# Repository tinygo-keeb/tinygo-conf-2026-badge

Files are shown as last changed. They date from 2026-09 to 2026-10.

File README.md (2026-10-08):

# TinyGo Conf 2026 Badge

[English](README.en.md)

TinyGo Conference 2026 向けバッジのハードウェア設計と TinyGo ファームウェアをまとめたリポジトリです。ESP32-S3-DevKit を中心に、ディスプレイ、入力デバイス、音声、赤外線、温湿度センサーなどを搭載しています。

## 主な機能

| 機能 | ハードウェア | ファームウェアの例 |
| --- | --- | --- |
| 表示 | ST7789 ディスプレイ | [`display`](firmware/examples/display)、[`demo`](firmware/examples/demo) |
| 入力 | ジョイスティック、スイッチ × 2 | [`input`](firmware/examples/input)、[`rhythm`](firmware/examples/rhythm) |
| 光と音 | RGB LED × 2、MAX98357 アンプとスピーカー | [`blink`](firmware/examples/blink)、[`audio`](firmware/examples/audio) |
| センサー・拡張 | AHT21B 温湿度センサー、Grove 互換 I2C コネクタ | [`aht21b`](firmware/examples/aht21b)、[`i2cscan`](firmware/examples/i2cscan) |
| 赤外線 | 赤外線 LED・受信モジュール | [`ir`](firmware/examples/ir)、[`irlearn`](firmware/examples/irlearn) |
| 無線通信 | ESP32-S3 の Wi-Fi・BLE | [`wifi-server`](firmware/examples/wifi-server)、[`ble-sensor`](firmware/examples/ble-sensor) |

全体の動作確認には [`selftest`](firmware/examples/selftest) を使えます。

## 組み立て

必要な部品と写真付きの組み立て手順は [ビルドガイド](hardware/build/build.md) を参照してください。

## ドキュメントとファイル

| パス | 内容 |
| --- | --- |
| [hardware/README.md](hardware/README.md) | 基板の構成、KiCad のセットアップ、製造データ |
| [hardware/build/build.md](hardware/build/build.md) | 部品一覧と写真付きの組み立て手順 |
| [hardware/tinygo-conf-2026.kicad_pro](hardware/tinygo-conf-2026.kicad_pro) | KiCad プロジェクト。回路図と基板レイアウトは同じディレクトリにあります |
| [firmware/README.md](firmware/README.md) | ビルド・書き込み方法、サンプル一覧、ピン割り当て、実装上の注意点 |
| [firmware/Makefile](firmware/Makefile) | サンプルのビルド確認や Wi-Fi サンプルの書き込み |

## 使い始める

### ハードウェア

KiCad 9.0 以降を使用します。KiCad ライブラリの一部はサブモジュールなので、リポジトリのルートで取得してください。

```sh
git submodule update --init --recursive
```

[KiCad プロジェクト](hardware/tinygo-conf-2026.kicad_pro) を開き、バッジの組み立てには [組み立てガイド](hardware/build/build.md) を参照してください。

### ファームウェア

TinyGo を用意し、ESP32-S3-DevKit を接続して以下を実行します。

```sh
cd firmware
tinygo flash --target esp32s3-box-3 --size short ./examples/blink
tinygo monitor --target esp32s3-box-3
```

全サンプルのビルド確認は `firmware/` で `make smoketest` を実行します。Wi-Fi・BLE の設定や各サンプルの使い方は [ファームウェアのREADME](firmware/README.md) を参照してください。

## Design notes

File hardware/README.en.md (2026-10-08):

# Hardware (tinygo-conf-2026)

[日本語](README.md)

This KiCad project defines the development board for TinyGo Conference 2026. It brings the display, audio, and input devices together on one board around an ESP32-S3-DevKit.

## Main components and features

- **ESP32-S3-DevKit** — main board mounted through pin sockets
- **ST7789 display** — SPI connection (CS / DC / RES / SCL / DIN), 8-pin connector
- **MAX98357 (Adafruit)** — I2S audio amplifier (BCLK / LRC / DIN) and speaker
- **Two RGB LEDs** — connected in series
- **Analog joystick (ALPS RKJXV122400R)** — X/Y axes and push button
- **Two push switches**
- **Infrared LED and receiver** — IR_LED / IR_DATA
- **4-pin I2C connector** — for external modules, with a Grove-compatible footprint
- **AHT21B** — temperature and humidity sensor

## Files

| Path | Description |
| --- | --- |
| `tinygo-conf-2026.kicad_pro` | KiCad project file |
| `tinygo-conf-2026.kicad_sch` | Schematic |
| `tinygo-conf-2026.kicad_pcb` | PCB layout |
| `tinygo-conf-2026-devkit/` | Manufacturing Gerber and drill files |
| `lib/` | Symbol and footprint libraries, including the submodules listed below |
| `lib/sglib.kicad_sym`, `lib/sglib.pretty/` | Custom libraries for the joystick, Grove connector, and other parts |
| `fp-lib-table`, `sym-lib-table` | Project library tables |

## Requirements

- KiCad 9.0 or later

## Setup

Some libraries are managed as Git submodules. Run this command from the repository root:

```sh
git submodule update --init --recursive
```

Then open `hardware/tinygo-conf-2026.kicad_pro` in KiCad.

### Submodules

| Path | Purpose | Source |
| --- | --- | --- |
| `lib/espressif` | ESP32 symbols | espressif/kicad-libraries |
| `lib/kbd` | ESP32-S3-DevKit symbols and more | foostan/kbd |
| `lib/MAX98357` | MAX98357 amplifier | besi/kicad-adafruit-MAX98357 |
| `lib/st7789` | ST7789 display | BennyLuca/Kicad_Components_Library |
| `lib/sparkfun` | SparkFun library | sparkfun/SparkFun-KiCad-Libraries |

## Manufacturing files

The `tinygo-conf-2026-devkit/` directory contains the complete two-layer board output: front and back copper, solder mask, paste, silkscreen, board outline, and PTH/NPTH drill files.

## Assembly

See the [build guide](build/build.en.md) for the parts list and illustrated instructions.

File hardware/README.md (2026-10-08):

# ハードウェア (tinygo-conf-2026)

[English](README.en.md)

TinyGo Conference 2026 向け開発ボード (devkit) の KiCad プロジェクトです。
ESP32-S3-DevKit を中心に、ディスプレイ・オーディオ・入力デバイスなどを 1 枚の基板にまとめています。

## 主な搭載部品・機能

- **ESP32-S3-DevKit** — メインボード (ピンソケット経由で搭載)
- **ST7789 ディスプレイ** — SPI 接続 (CS / DC / RES / SCL / DIN)、8 ピンコネクタ
- **MAX98357 (Adafruit)** — I2S オーディオアンプ (BCLK / LRC / DIN) + スピーカー
- **RGB LED × 2** — シリアル接続
- **アナログジョイスティック (ALPS RKJXV122400R)** — X / Y 軸 + プッシュボタン
- **プッシュスイッチ × 2**
- **赤外線 LED / 赤外線受信** — IR_LED / IR_DATA
- **I2C コネクタ (4 ピン)** — 外部モジュール接続用 (Grove 互換フットプリントあり)
- **AHT21B** — 温湿度センサー

## ファイル構成

| パス | 内容 |
| --- | --- |
| `tinygo-conf-2026.kicad_pro` | KiCad プロジェクトファイル |
| `tinygo-conf-2026.kicad_sch` | 回路図 |
| `tinygo-conf-2026.kicad_pcb` | 基板レイアウト |
| `tinygo-conf-2026-devkit/` | 製造用ガーバー・ドリルデータ |
| `lib/` | シンボル / フットプリントライブラリ (下記サブモジュール含む) |
| `lib/sglib.kicad_sym`, `lib/sglib.pretty/` | 自作ライブラリ (ジョイスティック、Grove コネクタなど) |
| `fp-lib-table`, `sym-lib-table` | プロジェクト用ライブラリテーブル |

## 必要環境

- KiCad 9.0 以降

## セットアップ

ライブラリの一部は git サブモジュールとして管理しています。リポジトリのルートで以下を実行してください。

```sh
git submodule update --init --recursive
```

その後 `hardware/tinygo-conf-2026.kicad_pro` を KiCad で開きます。

### サブモジュール一覧

| パス | 用途 | 取得元 |
| --- | --- | --- |
| `lib/espressif` | ESP32 系シンボル | espressif/kicad-libraries |
| `lib/kbd` | ESP32-S3-Devkit シンボルなど | foostan/kbd |
| `lib/MAX98357` | MAX98357 アンプ | besi/kicad-adafruit-MAX98357 |
| `lib/st7789` | ST7789 ディスプレイ | BennyLuca/Kicad_Components_Library |
| `lib/sparkfun` | SparkFun ライブラリ | sparkfun/SparkFun-KiCad-Libraries |

## 製造データ

`tinygo-conf-2026-devkit/` に 2 層基板のガーバーデータ (表裏の銅箔・レジスト・ペースト・シルク、外形、PTH/NPTH ドリル) 一式が出力済みです。

## 組み立て

部品一覧と写真付きの手順は [組み立てガイド](build/build.md) を参照してください。

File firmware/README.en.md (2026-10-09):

# Firmware

[日本語](README.md)

TinyGo firmware for the TinyGo Conference 2026 badge, based on the ESP32-S3-DevKit.

## Build and flash

From the repository root:

```sh
cd firmware
tinygo flash --target esp32s3-box-3 --size short ./examples/blink
tinygo monitor --target esp32s3-box-3
```

The `smoketest` target in `Makefile` lists the build command for each example on its own line. Run `make smoketest` to build them all into `out/`. To flash an example, copy its line and replace `build -o ./out/xxx.bin` with `flash`.

Wi-Fi examples embed the SSID and password at build time. The Makefile uses `YOUR_SSID` and `YOUR_PASSWORD` placeholders. Replace them with your values, or use `make flash-wifi-<name>` to supply credentials through Make variables or environment variables:

```sh
make flash-wifi-server SSID=yourssid PASS=yourpassword
# Environment variables also work (WIFI_SSID / WIFI_PASS, or SSID / PASS).
export WIFI_SSID=yourssid WIFI_PASS=yourpassword
make flash-wifi-server
# Manual command:
CGO_CFLAGS_ALLOW=-fno-short-enums tinygo flash --target esp32s3-box-3 --size short \
  -ldflags="-X main.ssid=yourssid -X main.password=yourpassword" ./examples/wifi-server
```

With TinyGo 0.43 or later, BLE examples build with the standard target used in the Makefile. Older TinyGo versions need the custom target `targets/esp32s3-box-3-ble.json` and `-tags espradio`. Run these commands from `firmware/` because the linker script path is relative to that directory. Add `-tags bledebug` to print Bluetooth ATT/HCI debug output over serial.

```sh
CGO_CFLAGS_ALLOW=-fno-short-enums tinygo flash --target esp32s3-box-3 --size short ./examples/ble-sensor
# For older TinyGo versions:
CGO_CFLAGS_ALLOW=-fno-short-enums tinygo flash --target ./targets/esp32s3-box-3-ble.json \
  -tags espradio --size short ./examples/ble-sensor
```

## Layout

| Path | Description |
| --- | --- |
| `badge/` | Pin assignments and helpers for initializing peripherals |
| `ws2812s3/` | WS2812B driver for the ESP32-S3 at 240 MHz |
| `i2s/` | 16-bit stereo audio output driver using ESP32-S3 I2S0 and GDMA |
| `wifi/` | Helper for connecting through espradio; resets and retries after a failure |
| `flashstore/` | Settings storage that reads and writes 64 KB of SPI flash starting at 0x1F0000 through ROM functions |
| `targets/` | Custom BLE target with an upstream TinyGo esp32s3.ld linker script |
| `examples/blink` | Cycle the WS2812B LEDs through rainbow colors |
| `examples/all` | Launcher for all 20 examples: logo on startup, SW1 opens the menu, joystick up/down selects, SW1 or joystick press starts, holding SW1+SW2 for one second returns from an example to the menu, and left in the menu returns to TOP. Menu movement uses buffered partial updates. See [the launcher README](examples/all/README.md) for build commands and controls. |
| `examples/display` | Show color bars and text on the ST7789 |
| `examples/input` | Print the SW1/SW2 and joystick states over serial |
| `examples/joyraw` | Measure raw joystick values and movement limits (min/max) |
| `examples/aht21b` | Print temperature and humidity readings |
| `examples/i2cscan` | Scan the Grove and AHT21B I2C buses |
| `examples/dht20` | Print readings from a Grove-connected DHT20 (AHT20-compatible) sensor |
| `examples/wifi-httpget` | Connect to Wi-Fi and fetch http://httpbin.org/get using net/http |
| `examples/wifi-server` | Serve AHT21B temperature and humidity readings over HTTP using httphi |
| `examples/wifi-joystick` | Show joystick X/Y and switch states live in a browser |
| `examples/ble-scanner` | Scan nearby BLE devices and print addresses, RSSI, and names |
| `examples/ble-sensor` | BLE peripheral with temperature and humidity (Environmental Sensing), color writes for two WS2812B LEDs, button notifications, and automatic/manual LED modes. Shows the chip-specific ID in its name and on the LCD |
| `examples/ble-sensor/webble.html` | Web Bluetooth control page for the BLE peripheral; open it in Chrome or Edge. It is also published at https://conf.tinygo-keeb.org/2026/conf2026badge/ |
| `examples/ir` | Receive NEC infrared signals and send one when a button is pressed |
| `examples/irlearn` | Learn, list, name, delete, save, and retransmit remote-control signals |
| `examples/audio` | Play notes, melodies, and beeps through the MAX98357 |
| `examples/audiotest` | Print I2S diagnostics and continuously play a 1 kHz sine wave |
| `examples/demo` | Full-feature demo combining the features above |
| `examples/rhythm` | Rhythm game: press five controls (joystick left, up or down, right, SW2, and SW1) as notes fall. The BGM is synthesized live; pitch corresponds to lane, and effects grow with the combo. EASY / NORMAL modes |
| `examples/slotgame` | Three-reel slot game controlled entirely with button_1 (SW1). Press to start, then press again to stop each reel from left to right. See [the game README](examples/slotgame/README.md) for controls and build commands. |
| `examples/selftest` | Check all onboard devices together. Buttons, joystick directions, AHT21B, infrared loopback, and I2S are checked automatically; the display shows ALL OK when complete. Check the LCD, LEDs, speaker, and Grove by sight or sound |

## Pin assignments

These assignments come from `../hardware/tinygo-conf-2026.kicad_sch`. Constants are in `badge/badge.go`.

| Function | Signal | GPIO | Notes |
| --- | --- | --- | --- |
| LCD ST7789 (J3) | SCL | 12 | SPI0 (FSPI) |
| | SDA (MOSI) | 11 | |
| | CS | 10 | |
| | DC | 5 | |
| | RES | 4 | |
| | BLK | - | Connected directly to 3V3 |
| I2S MAX98357 (U3) | BCLK | 45 | I2S0 (see below) |
| | LRC | 21 | |
| | DIN | 47 | |
| WS2812B x2 (D1, D2) | DIN | 16 | D1 -> D2 in series |
| Joystick (U2) | X | 7 | ADC1_CH6 |
| | Y | 6 | ADC1_CH5 |
| | BTN | 15 | Grounded when pressed; internal pull-up |
| SW1 | | 13 | Grounded when pressed; internal pull-up |
| SW2 | | 14 | Grounded when pressed; internal pull-up |
| IR LED (D5) | | 17 | High turns it on; modulated with 38 kHz PWM |
| IR receiver (J2) | DATA | 18 | |
| Grove I2C (J1) | SDA | 8 | I2C0 |
| | SCL | 9 | |
| AHT21B (J4) | SDA | 41 | I2C1 |
| | SCL | 42 | |

Expansion header J5 (2x8):

```
 1: 3V3     2: 3V3
 3: GPIO1   4: GPIO2
 5: GPIO3   6: GPIO38
 7: GPIO39  8: GND
 9: GND    10: GPIO40
11: GPIO41 12: GPIO42   (shared with AHT21B SDA/SCL)
13: GPIO45 14: GPIO46   (GPIO45 is shared with I2S BCLK)
15: GPIO48 16: VCC (5V)
```

## Notes

- **Target:** Use `esp32s3-box-3`. The `esp32s3-generic` target does not define
  `machine.CPUFrequency()` or the default SPI pins, so some drivers cannot build.
- **WS2812B:** On Xtensa, `tinygo.org/x/drivers/ws2812` only supports 80 and 160 MHz.
  The ESP32-S3 runs at 240 MHz, so `ws2812s3/` provides a bit-banging driver
  with timing for 240 MHz.
- **LCD flicker:** Drawing directly to the display makes individual updates
  visible. `badge.NewFramebuffer(display)` creates a full-screen offscreen
  buffer (RGB565, about 115 KB). Draw there, then call `Display()` to transfer
  it in one pass (see `examples/demo`). The buffer can also be passed directly
  to tinyfont and tinydraw.
- **I2C initialization:** During its final bus-clear step,
  `machine.I2C.Configure` waits indefinitely for a completion bit and may hang
  on a floating bus without pull-ups. Configure also overwrites pin settings,
  removing any internal pull-ups enabled beforehand. `badge.ConfigureI2C()`
  implements the same sequence with internal pull-up support and a finite
  wait. Both Grove (`ConfigureGroveI2C`, with internal pull-ups at 100 kHz)
  and AHT21B (`ConfigureSensorI2C`) use it.
- **I2C scanning:** TinyGo's ESP32 I2C driver does not report an address NACK
  as an error on reads. On writes, after a NACK it leaves unsent data in the
  TX FIFO, causing the next transaction to become a general call, which the
  AHT21B acknowledges. `badge.ProbeI2C()` therefore sends only the address
  byte through direct register access, then calls `badge.ResetI2C()` to reset
  the FSM and FIFO after a failure.
- **Joystick travel:** The joystick cap limits its movement. Raw ADC readings
  travel only about ±16000 to 17000 counts around the center, roughly half the
  full 0..65535 range. `badge.Joystick` normalizes with `Range` (default 16000),
  so a full deflection reaches 1000. If the range differs, measure it with
  `examples/joyraw` and adjust `Range`. Stationary noise is about ±100 counts,
  so `DeadZone` is set to 50 (equivalent to 800 counts).
- **USB serial:** Output from `print` is not sent until a newline. Long
  operations without a newline may appear to produce no output; use `println`
  at checkpoints.
- **Output in interrupts:** Callbacks such as those in infrared reception
  (irremote) run inside GPIO interrupts. Calling `println` there can stall USB
  serial output. Save the data in the callback and print it from the main
  loop instead (see `examples/ir`).
- **Flash storage:** TinyGo's machine package has no ESP32-S3 flash API.
  `flashstore/` calls the fixed-address ROM functions
  `esp_rom_spiflash_read/write/erase_sector/unlock` directly through CGo;
  the addresses come from ESP-IDF v5.1.2's esp32s3.rom.ld. It follows the
  same procedure as TinyGo's ESP32-C3 driver and calls the ROM functions
  with interrupts disabled. TinyGo writes 2 MB as the flash size in the image
  header, so the ROM driver rejects erase/write operations above 2 MB.
  The settings area therefore occupies the final 64 KB below 2 MB,
  starting at 0x1F0000. Reads also use ROM functions instead of the cache.
- **I2S (MAX98357):** TinyGo's machine package does not support ESP32-S3 I2S.
  The implementation in `i2s/` accesses registers directly, following the
  procedure from ESP-IDF v5.1's i2s_ll.h, gdma_ll.h, and i2s_std.c. ESP32-S3
  I2S can send data only through GDMA, so DMA buffers form a ring for
  continuous playback; `Write` fills them in turn. The ring keeps playing,
  so call `Silence()` (or `Stop()` on a `badge.ToneGenerator`) after playback.
  The format is Philips standard, 16-bit, two channels, MCLK = fs*256, and
  BCLK = fs*32 (16-bit slots; `Config.SlotBits` also allows 32). GDMA uses
  channel 0.
- **Wi-Fi:** The firmware uses `tinygo.org/x/espradio` (TinyGo 0.41 or later),
  which combines Espressif binary blobs with lneto, a pure-Go TCP/IP stack.
  The espradio C code requires `-fno-short-enums`, so builds need
  `CGO_CFLAGS_ALLOW=-fno-short-enums`; relevant Makefile lines set it.
  Embed the SSID and password with
  `-ldflags="-X main.ssid=... -X main.password=..."`. Without them, the
  example repeatedly reports `failure: ssid is empty` at startup. Wi-Fi
  code is then eliminated as dead code, making the binary unusually small.
  The HTTP server uses espradio's recommended `httphi`, which does not
  allocate heap space per request. `net/http` allocates about 10 KB per
  connection and can stall after long runs due to GC fragmentation (see
  espradio's README). Wireless initialization can happen only once: calling
  `NetConnect` again after a failure returns `already enabled`.
  `wifi.Connect()` waits five seconds after a failure, then soft-resets the
  chip with `badge.Reset()` and starts over. Just after closing a monitor,
  a previous session can remain on the access point and cause
  `auth expired`; this retry handles it. Merely importing espradio links
  initialization data even if unused, increasing flash use by about 170 KB
  and RAM use by about 160 KB. For that reason, Wi-Fi helpers live in
  the separate `wifi` package instead of `badge`.
- **BLE:** The firmware uses the espradio backend of
  `tinygo.org/x/bluetooth` (build tag `espradio`). TinyGo 0.43 and later
  apply that tag to ESP32 targets by default and include ESP32-S3 BT ROM
  symbols in the linker script, so the standard target works. Older
  versions, such as 0.42.0-dev, lack both and fail to link because the BLE
  blob (libbtdm_app.a) references about 1,000 ROM symbols, including
  `r_osi_funcs_p`. To support them, this repository includes upstream
  TinyGo's esp32s3.ld (retrieved from the dev branch on 2026-09-25) as
  `targets/esp32s3-ble.ld`. The custom target
  `targets/esp32s3-box-3-ble.json` inherits from esp32s3-box-3 and uses that
  script. With older TinyGo, specify this target and `-tags espradio`.
  The `linkerscript` path in a TinyGo target JSON is resolved relative to
  the current working directory (`firmware/`).
- **Badge identification:** `badge.SerialNumber()` returns a six-digit
  hexadecimal ID from the low three bytes of the chip-specific eFuse MAC
  address. The ble-sensor example advertises as
  `TinyGo Conf 2026 #XXXXXX` and displays the same ID on the LCD, making it
  possible to distinguish badges used together in a workshop.
- **Where espradio is imported:** TinyGo runs package initializers in
  lexicographic import-path order. After an initializer that cannot be
  evaluated at compile time (an espradio C call), subsequent package
  initializers run at runtime instead. This module's import path
  (`github.com/sago35/...`) sorts before `github.com/soypat/lneto` and
  `net/http`. Importing espradio from this module would move Unicode table
  initialization and similar work to runtime, increasing RAM use by about
  70 KB (measured: 115 KB to 240 KB). Therefore `wifi.Connect()` accepts
  a `netlink.Netlinker` rather than importing espradio, and each example's
  main package creates the `Esplink`.
- **MAX98357 SD pin:** The pin is unconnected in the schematic. On an
  Adafruit module, its onboard 1 MΩ pull-up puts SD at about 0.45 V with
  Vin = 5 V (stereo average mode), but some modules did not work in this
  configuration. A module with SD tied directly to Vin (left channel only)
  was tested successfully. The firmware sends the same audio on L and R,
  so both modes sound the same. A future board revision should provide
  the SD pull-up on the board.

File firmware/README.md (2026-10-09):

# firmware

[English](README.en.md)

TinyGo Conference 2026 バッジ (ESP32-S3-DevKit ベース) の TinyGo ファームウェア。

## ビルド・書き込み

```sh
cd firmware
tinygo flash --target esp32s3-box-3 --size short ./examples/blink
tinygo monitor --target esp32s3-box-3
```

`Makefile` の `smoketest` に全 example のビルドコマンドを 1 行ずつそのまま書いてある
(`make smoketest` で全部ビルドして `out/` に出力する)。書き込みたいときは該当する行を
コピーして、`build -o ./out/xxx.bin` を `flash` に変えて実行する。

Wi-Fi の example は SSID とパスワードをビルド時に埋め込む。Makefile の行は
`YOUR_SSID` / `YOUR_PASSWORD` のプレースホルダなので、自分のものに書き換えるか、
環境変数から埋め込む `make flash-wifi-<name>` を使う。

```sh
make flash-wifi-server SSID=yourssid PASS=yourpassword
# 環境変数でも可 (WIFI_SSID / WIFI_PASS、または SSID / PASS)
export WIFI_SSID=yourssid WIFI_PASS=yourpassword
make flash-wifi-server
# 手動なら
CGO_CFLAGS_ALLOW=-fno-short-enums tinygo flash --target esp32s3-box-3 --size short \
  -ldflags="-X main.ssid=yourssid -X main.password=yourpassword" ./examples/wifi-server
```

BLE の example は TinyGo 0.43 以降なら Makefile の行のとおり通常のターゲットでビルドできる。
それより古い TinyGo では専用ターゲット (`targets/esp32s3-box-3-ble.json`) と
`-tags espradio` を指定する (firmware/ で実行。リンカスクリプトのパスは firmware/ からの相対)。
`-tags bledebug` を足すと bluetooth パッケージのデバッグ出力 (ATT/HCI の処理) がシリアルに出る。

```sh
CGO_CFLAGS_ALLOW=-fno-short-enums tinygo flash --target esp32s3-box-3 --size short ./examples/ble-sensor
# 古い TinyGo なら
CGO_CFLAGS_ALLOW=-fno-short-enums tinygo flash --target ./targets/esp32s3-box-3-ble.json \
  -tags espradio --size short ./examples/ble-sensor
```

## 構成

全サンプルを選択して実行するには `make flash-all` を使う。
`examples/all` は起動時にロゴを表示し、SW1で選択画面、Joystick上下で選択、
SW1またはJoystick押し込みで起動する。実行中はSW1＋SW2を1秒同時長押しして選択画面へ戻り、
選択画面でJoystick左に倒すとTOPへ戻る。
Wi-Fi設定や統合版での入力の違いは [examples/all/README.md](examples/all/README.md) を参照。

| パス | 内容 |
| --- | --- |
| `badge/` | ピン割り当てと各ペリフェラルの初期化ヘルパー |
| `ws2812s3/` | ESP32-S3 (240MHz) 用 WS2812B ドライバ |
| `i2s/` | ESP32-S3 の I2S0 + GDMA を使った 16bit ステレオ音声出力ドライバ |
| `wifi/` | espradio で Wi-Fi に接続するヘルパー (失敗時はリセットして再試行) |
| `flashstore/` | ROM 関数で SPI フラッシュの一部 (0x1F0000 から 64KB) を読み書きする設定保存用パッケージ |
| `targets/` | BLE 用のカスタムターゲット (アップストリーム TinyGo の esp32s3.ld を同梱) |
| `examples/blink` | WS2812B を虹色に点灯 |
| `examples/all` | 全20サンプルの統合ランチャー。ロゴ画面、Joystickで選択、実行中はSW1＋SW2を1秒同時長押しで選択画面へ戻る |
| `examples/display` | ST7789 にカラーバーと文字を表示 |
| `examples/input` | SW1/SW2 とジョイスティックの状態をシリアル出力 |
| `examples/joyraw` | ジョイスティックの生値と可動範囲 (min/max) を計測してシリアル出力 |
| `examples/aht21b` | 温湿度センサーの値をシリアル出力 |
| `examples/i2cscan` | Grove / AHT21B の I2C バスをスキャン |
| `examples/dht20` | Grove につないだ DHT20 (AHT20 互換) の温湿度をシリアル出力 |
| `examples/wifi-httpget` | Wi-Fi に接続して http://httpbin.org/get を取得 (net/http) |
| `examples/wifi-server` | Wi-Fi に接続して AHT21B の温湿度を返す HTTP サーバー (httphi) |
| `examples/wifi-joystick` | ジョイスティックの XY とスイッチの状態をブラウザにリアルタイム表示 |
| `examples/ble-scanner` | BLE で周囲のデバイスをスキャンしてアドレス、RSSI、名前を表示 |
| `examples/ble-sensor` | BLE ペリフェラル。温湿度 (Environmental Sensing)、WS2812B 2 個の色書き込み、ボタン通知、LED の自動/手動モード。名前と LCD にチップ固有の ID を表示 |
| `examples/ble-sensor/webble.html` | 上記に Web Bluetooth で接続して操作するページ (Chrome / Edge で開く)。https://conf.tinygo-keeb.org/2026/conf2026badge/ で公開している |
| `examples/ir` | 赤外線受信 (NEC) と、ボタン押下で赤外線送信 |
| `examples/irlearn` | リモコンの信号を学習して送信するアプリ。一覧、登録、名前編集、削除。フラッシュに保存 |
| `examples/audio` | MAX98357 から音階・メロディ・ビープを鳴らす |
| `examples/audiotest` | I2S の動作確認用。診断出力を出したあと 1kHz の正弦波を鳴らし続ける |
| `examples/demo` | 上記をまとめた全機能デモ |
| `examples/rhythm` | 音ゲー。上から降ってくるノーツに合わせて 5 つのキー (ジョイスティックの左、上か下、右と SW2、SW1) を押す。BGM はその場で合成し、メロディの音の高さとレーンが対応している。コンボ数に応じて画面の演出が増える。EASY / NORMAL |
| `examples/slotgame` | 3リールの目押しスロット。button_1（SW1）で開始し、押すたびに左 → 中央 → 右の順にリールを止める。[操作・ビルド方法](examples/slotgame/README.md) |
| `examples/selftest` | 基板上の全デバイスを一度に動作確認するセルフテスト。ボタン、ジョイスティック上下左右、AHT21B、赤外線の自己受信、I2S を自動判定し、すべて済むと ALL OK。LCD、LED、スピーカー、Grove は画面の表示と音で目視確認 |

## ピン割り当て

`tinygo-conf-2026.kicad_sch` から抽出。定数は `badge/badge.go` にある。

| 機能 | 信号 | GPIO | 備考 |
| --- | --- | --- | --- |
| LCD ST7789 (J3) | SCL | 12 | SPI0 (FSPI) |
| | SDA (MOSI) | 11 | |
| | CS | 10 | |
| | DC | 5 | |
| | RES | 4 | |
| | BLK | - | 3V3 直結 |
| I2S MAX98357 (U3) | BCLK | 45 | I2S0 (後述) |
| | LRC | 21 | |
| | DIN | 47 | |
| WS2812B x2 (D1, D2) | DIN | 16 | D1 -> D2 直列 |
| ジョイスティック (U2) | X | 7 | ADC1_CH6 |
| | Y | 6 | ADC1_CH5 |
| | BTN | 15 | 押下で GND、内部プルアップ |
| SW1 | | 13 | 押下で GND、内部プルアップ |
| SW2 | | 14 | 押下で GND、内部プルアップ |
| 赤外線 LED (D5) | | 17 | High で点灯、PWM 38kHz で変調 |
| 赤外線受信 (J2) | DATA | 18 | |
| Grove I2C (J1) | SDA | 8 | I2C0 |
| | SCL | 9 | |
| AHT21B (J4) | SDA | 41 | I2C1 |
| | SCL | 42 | |

拡張ヘッダ J5 (2x8):

```
 1: 3V3     2: 3V3
 3: GPIO1   4: GPIO2
 5: GPIO3   6: GPIO38
 7: GPIO39  8: GND
 9: GND    10: GPIO40
11: GPIO41 12: GPIO42   (AHT21B SDA/SCL と共用)
13: GPIO45 14: GPIO46   (GPIO45 は I2S BCLK と共用)
15: GPIO48 16: VCC (5V)
```

## 注意点

- **ターゲット**: `esp32s3-box-3` を使う。`esp32s3-generic` は `machine.CPUFrequency()`
  や SPI のデフォルトピンが定義されておらず、drivers の一部がビルドできない。
- **WS2812B**: `tinygo.org/x/drivers/ws2812` は xtensa では 80/160MHz のみ対応で、
  ESP32-S3 は 240MHz で動作するため使えない。`ws2812s3/` に 240MHz 用の
  タイミングでビットバンギング実装を置いている。
- **LCD のちらつき**: ディスプレイに直接描くと部分ごとの書き換えが見えてちらつく。
  `badge.NewFramebuffer(display)` で 1 画面分 (RGB565、約 115KB) のオフスクリーンバッファを
  作り、そこに描いてから `Display()` で一括転送する (`examples/demo` 参照)。tinyfont や
  tinydraw の描画先としてそのまま渡せる。
- **I2C 初期化**: `machine.I2C.Configure` は最後のバスクリアで完了ビットを無限に待つため、
  プルアップのない (浮いた) バスでは止まることがある。また Configure はピン設定を上書きするので
  事前に内部プルアップを有効にしても外れる。`badge.ConfigureI2C()` は同じ手順を内部プルアップ
  対応と有限待ちで自前実装したもので、Grove (`ConfigureGroveI2C`、内部プルアップ有効、100kHz) と
  AHT21B (`ConfigureSensorI2C`) はこれを使う。
- **I2C スキャン**: TinyGo の ESP32 I2C ドライバは読み出し時のアドレス NACK をエラーにせず、
  書き込みでは NACK 後に未送信データが TX FIFO に残って次のトランザクションがジェネラルコール
  になる (AHT21B はこれに ACK する)。そのため `badge.ProbeI2C()` はレジスタを直接操作して
  アドレスバイトのみを送り、失敗時は `badge.ResetI2C()` で FSM と FIFO をリセットしている。
- **ジョイスティックの可動範囲**: スティックはハット側で可動範囲を絞ってあり、ADC の生値は中心から
  ±16000..17000 カウント (全域 0..65535 の約半分) しか動かない。`badge.Joystick` は `Range` (既定 16000)
  で正規化するので、いっぱい倒すと 1000 に届く。範囲が変わったら `examples/joyraw` で計測して `Range` を直す。
  静止時のノイズは ±100 カウント程度なので `DeadZone` は 50 (= 800 カウント) にしてある。
- **USB シリアル**: `print` の出力は改行まで送られない。改行なしで長い処理をすると
  何も表示されないように見えるので、区切りには `println` を使う。
- **割り込み内での出力**: 赤外線受信 (irremote) などのコールバックは GPIO 割り込みの中で呼ばれる。
  その中で `println` を使うと USB シリアル出力が止まることがあるので、割り込み内ではデータを
  保存するだけにしてメインループで出力する (`examples/ir` 参照)。
- **フラッシュへの保存**: TinyGo の machine パッケージには ESP32-S3 用のフラッシュ API が無いので、
  `flashstore/` は ROM に固定アドレスで存在する `esp_rom_spiflash_read/write/erase_sector/unlock`
  を CGo から直接呼ぶ (アドレスは ESP-IDF v5.1.2 の esp32s3.rom.ld)。手順は TinyGo の
  ESP32-C3 用ドライバと同じで、割り込み禁止のまま ROM 関数を呼ぶ。TinyGo のイメージヘッダは
  フラッシュサイズを 2MB と書くので ROM ドライバは 2MB を超える erase/write を拒否する。そのため
  保存領域は 2MB 未満の末尾 (0x1F0000 から 64KB) に置く。読み出しもキャッシュ経由ではなく
  ROM 関数で行う。
- **I2S (MAX98357)**: TinyGo の machine パッケージは ESP32-S3 の I2S を未サポート。
  `i2s/` にレジスタ直叩きで実装している (ESP-IDF v5.1 の i2s_ll.h / gdma_ll.h / i2s_std.c の
  手順を移植)。ESP32-S3 の I2S は GDMA 経由でしか送れないため、DMA バッファをリング状につないで
  連続送信し、`Write` はそのバッファを順に埋める。リングは再生され続けるので、鳴らし終えたら
  `Silence()` (badge.ToneGenerator なら `Stop()`) で無音にすること。フォーマットは Philips 標準、
  16bit、2ch、MCLK = fs*256、BCLK = fs*32 (スロット幅 16。`Config.SlotBits` で 32 も可)。
  GDMA はチャネル 0 を使う。
- **Wi-Fi**: `tinygo.org/x/espradio` (TinyGo 0.41 以降、Espressif のバイナリブロブ + 純 Go の
  TCP/IP スタック lneto) を使う。espradio の C コードが `-fno-short-enums` を要求するので、
  ビルド時に環境変数 `CGO_CFLAGS_ALLOW=-fno-short-enums` が必要 (Makefile の該当行に前置してある)。
  SSID/パスワードは `-ldflags="-X main.ssid=... -X main.password=..."` で埋め込む。埋め込まないと
  example は起動時に `failure: ssid is empty` を繰り返す (このとき Wi-Fi のコードは
  デッドコードとして落ちるので、バイナリが極端に小さくなる)。HTTP サーバーは espradio 推奨の
  `httphi` (リクエストごとにヒープを使わない) を使う。`net/http` は接続ごとに約 10kB を
  ヒープに確保するため、長時間動かすと GC の断片化で止まることがある (espradio の README 参照)。
  espradio は無線の初期化を一度しかできず、接続に失敗したあと `NetConnect` を呼び直しても
  `already enabled` で失敗する。`wifi.Connect()` は失敗時に 5 秒待ってチップをソフトリセット
  (`badge.Reset()`) し、最初からやり直す。モニタを閉じた直後などは AP 側に前のセッションが残って
  `auth expired` になることがあるが、この再試行でつながる。
  espradio を import するだけで (使わなくても) 初期化データがリンクされ、フラッシュ約 170KB、
  RAM 約 160KB が増えるので、Wi-Fi のヘルパーは `badge` ではなく別パッケージ `wifi` に置いている。
- **BLE**: `tinygo.org/x/bluetooth` の espradio バックエンド (ビルドタグ `espradio`) を使う。
  TinyGo 0.43 以降は ESP32 ターゲットに `espradio` タグが標準で付き、ESP32-S3 の BT ROM
  シンボルもリンカスクリプトに含まれるので、通常のターゲットでビルドできる。
  それより古い TinyGo (0.42.0-dev など) ではどちらも無く、espradio の BLE ブロブ
  (libbtdm_app.a) が参照する ROM シンボル (`r_osi_funcs_p` など約 1000 個) でリンクに失敗する。
  その場合のために、アップストリーム TinyGo (dev ブランチ、2026-09-25 取得) の `esp32s3.ld` を
  `targets/esp32s3-ble.ld` として同梱し、`targets/esp32s3-box-3-ble.json` (esp32s3-box-3 を継承)
  から参照している。古い TinyGo ではこのカスタムターゲットと `-tags espradio` を指定する。
  TinyGo のターゲット JSON の `linkerscript` は cwd (firmware/) からの相対パスで解決される。
- **バッジの識別**: `badge.SerialNumber()` は eFuse の MAC アドレス (チップ固有) の下位 3 バイトを
  16 進 6 桁にした ID を返す。ble-sensor はアドバタイズ名を `TinyGo Conf 2026 #XXXXXX` にし、
  同じ ID を LCD に表示するので、ワークショップで複数のバッジが同時に動いていても見分けられる。
- **espradio の import 位置**: TinyGo はパッケージの init を import パスの辞書順に実行し、
  コンパイル時に評価できない init (espradio の C 呼び出し) に当たると、それ以降のパッケージの
  init を実行時に回す。このモジュール (`github.com/sago35/...`) は `github.com/soypat/lneto` や
  `net/http` より辞書順で前なので、このモジュール内のパッケージから espradio を import すると
  unicode などのテーブル初期化が実行時に回り、RAM が約 70KB 増える (実測: 115KB → 240KB)。
  そのため `wifi.Connect()` は espradio を import せず `netlink.Netlinker` を受け取り、
  `Esplink` の生成は example の main で行う。
- **MAX98357 の SD ピン**: 回路図では未接続。Adafruit 製モジュールは基板上の 1MΩ でプルアップされ
  Vin=5V なら SD が約 0.45V (ステレオ平均モード) になるが、これで動かない個体があった。
  SD を Vin に直結 (左チャネルのみ) したモジュールで動作確認済み。ファームウェアは L/R に同じ
  データを流すのでどちらのモードでも音は同じ。次の基板では SD のプルアップを基板側に持たせたい。

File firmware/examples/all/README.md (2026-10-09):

# all

`firmware/examples` の20本を、1つのファームウェアから選択して実行します。
`slotgame` は3リールの目押しスロットです。button_1（SW1）で開始し、押すたびに
左 → 中央 → 右の順にリールを止めます（[操作説明](../slotgame/README.md)）。

## 操作

| 画面 | 操作 | 動作 |
| --- | --- | --- |
| TOP | 起動時 | `img/logo.jpg` を240×240のLCDに表示 |
| TOP | `button_1` / SW1 | プログラム選択画面を開く |
| 選択画面 | Joystick 上・下 | 選択を移動。長く倒すと連続移動し、一覧の端で折り返す |
| 選択画面 | SW1 またはJoystick押し込み | 選択中のプログラムを起動 |
| 選択画面・起動待ち | Joystick 左 | TOPへ戻る |
| プログラム実行中 | SW1＋SW2を1秒同時長押し | 本体をリセットしてプログラム選択画面へ戻る |

起動時はJoystickを中立にしてください。プログラムを選んだ後も、ボタンと
Joystickを離してから実行を開始します。各プログラムのSW1/SW2などの操作は
元のexampleと同じです。シリアル出力だけのexampleでは、LCDに実行中の名前と
選択画面へ戻る操作を表示します。戻ると直前に実行していたプログラムが選択され、
Joystickとボタンを離してから次の操作を受け付けます。

実行中はJoystickの上下左右・押し込みを各プログラムで使えます。
`rhythm` の左レーンはJoystick左、`irlearn` の名前編集は左右でカーソル移動など、
単独版と同じ操作です。戻るときはSW1とSW2を両方押した状態で1秒待ち、
選択画面が表示されたらボタンを離してください。途中で片方を離すと長押しの
時間を数え直します。

選択の上下移動では全画面を消去せず、変更した行と選択番号を更新します。
文字と背景を約13.4KBのバッファに描き終えてから転送するため、スクロールでも
消去途中の画面が見えるちらつきを抑えます。

実行中のプログラムから戻る際は、音声DMA、赤外線割り込み、HTTPサーバーや
BLE/Wi-Fiの処理を残さないため、本体をリセットします。戻り先と選択位置はRTCの
レジスタに一時的に保存し、再起動後に選択画面を開きます。通常の電源投入時は
ロゴ画面になります。`irlearn` の保存済み
データは残り、`rhythm` のベストスコアなどRAMだけの状態は初期化されます。
Wi-Fi接続失敗時も既存の `wifi.Connect` によるリセットでTOPへ戻ります。

## ビルド・書き込み

`firmware/` で実行します。全機能を含むため `CGO_CFLAGS_ALLOW` が必要です。

```sh
make build-all
make flash-all
tinygo monitor --target esp32s3-box-3
```

Wi-Fiを利用するときはSSIDとパスワードを指定します。3つのWi-Fiプログラムが
同じ設定を使います。未指定でもTOPや他のプログラムを利用でき、Wi-Fiを選ぶと
設定が必要であることをLCDに表示します。

```sh
make build-all SSID=yourssid PASS=yourpassword
make flash-all SSID=yourssid PASS=yourpassword
# WIFI_SSID / WIFI_PASS 環境変数でも指定できます。
```

手動でビルドする場合:

```sh
mkdir -p out
CGO_CFLAGS_ALLOW=-fno-short-enums tinygo build -o ./out/all.bin \
  --target esp32s3-box-3 --size short \
  -ldflags="-X main.ssid=yourssid -X main.password=yourpassword" ./examples/all
```

BLE用のROMシンボルを含まない古いTinyGoでは、既存のカスタムターゲットを使います。

```sh
CGO_CFLAGS_ALLOW=-fno-short-enums tinygo build -o ./out/all.bin \
  --target ./targets/esp32s3-box-3-ble.json -tags espradio --size short \
  -ldflags="-X main.ssid=yourssid -X main.password=yourpassword" ./examples/all
```

## 元のexample・ロゴを変更したとき

元のexampleはそれぞれ単独でビルドできます。`example_*.go` と `programs.go` は
元のソースを名前空間を分けて取り込んだ生成ファイルです。変更後は次を実行します。
新しいexampleも、隣のディレクトリに `main` 関数を置けば一覧に追加されます。
`*_test.go` は統合せず、`//go:embed` で指定された画像は `assets/<example>/` に
コピーします。画像の指定はワイルドカードを含まない相対ファイルパスにしてください。

```sh
go generate ./examples/all
```

`img/logo.jpg` は元画像です。生成処理では拡張子によらずJPEG/PNGの内容を判別し、
縦横比を保って240×240のRGB565に縮小した `img/logo.rgb565` を作ります。
ファームウェアにはこの約115KBの変換済み画像を埋め込みます。画像のデコードは
PCで行い、LCDへの転送は16行ずつなので、大きな元画像を本体のRAMに展開しません。

確認コマンド:

```sh
make check-all
make build-all SSID=buildcheck PASS=buildcheck
```

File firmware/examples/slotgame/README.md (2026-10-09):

# slotgame

[sat0ken/tinygo-slotgame](https://github.com/sat0ken/tinygo-slotgame) を
TinyGo Conference 2026 バッジ（ESP32-S3、ST7789 240×240）に移植した
3リールの目押しスロットです。

## 操作

| 操作 | 動作 |
| --- | --- |
| 停止中にbutton_1（SW1） | ゲーム開始（3クレジット消費） |
| 回転中にSW1を押す | 左 → 中央 → 右の順に、1回につき1リールを止める |
| GAME OVER中にSW1 | 50クレジットに戻す。もう一度押すとゲーム開始 |
| `all` から起動した場合、SW1＋SW2を1秒同時長押し | プログラム選択画面へ戻る |

ゲームの操作はすべてbutton_1（SW1）です。押すたびに一度離してください。
長押しでは次のリールは止まりません。リール下の `SW1` ラベルは、次に止める
リールが赤、順番待ちが暗い赤、停止したリールが灰色になります。
開始直後の300msは停止できません。

リール配列は固定で乱数は使いません。押してから次のコマ境界まで、最大1コマ
滑って停止します。中段の赤い線に図柄がそろうと、次の配当になります。

| 中段の役 | 配当 |
| --- | --- |
| 7 × 3 | 100 |
| BAR × 3 | 50 |
| TinyGoロゴ × 3 | 25 |
| 茶色のGopher × 3 | 15 |
| チェリー × 3 | 10 |
| 青いGopher × 3 | 8 |
| 左リールがチェリー | 2 |

TinyGoロゴは各リールに1個ずつ入っています。

最初に当てはまる役だけを払い出し、残りが3クレジット未満ならGAME OVERです。
クレジットはRAMに保持するため、電源を切ったり `all` の選択画面へ戻ったりすると
初期化されます。元のゲームと同様に効果音はありません。

## ビルド・書き込み

`firmware/` で実行します。

```sh
make build-slotgame
make flash-slotgame
# 手動で書き込む場合
tinygo flash --target esp32s3-box-3 --size short ./examples/slotgame
```

`make flash-all` で書き込む統合版にも `slotgame` が含まれます。

## テスト・画面確認

```sh
make check-slotgame
go test ./examples/slotgame -run 'TestPreview|TestTinyGoBonus' -preview -preview-dir /tmp/slotgame-preview
```

`slot.go` はハードウェアに依存せず、配当・停止位置・ボタンの押下・ゲーム進行・
描画範囲をホストのGoで検証できます。描画用RAMは図柄6枚とリール1本分の約63KBで、
全画面のフレームバッファは確保しません。

TinyGoロゴの元画像は `img/tinygo.png`、組み込み用の画像は `img/tinygo.rgba` です。
元画像を変更した場合は、次のコマンドで高さ44pxのスプライトを生成します。

```sh
cd examples/slotgame
GO111MODULE=off go run ./tools/gensprite -h 44 -o img/tinygo.rgba img/tinygo.png
cd ../..
go generate ./examples/all
```

## 移植元・画像のクレジット

ゲーム本体、テスト、Gopherスプライトの移植元は
[tinygo-slotgame の e61ecf541d6ef2643899a1041f0d8602801aa867](https://github.com/sat0ken/tinygo-slotgame/tree/e61ecf541d6ef2643899a1041f0d8602801aa867)
です。LCD初期化・ボタン入力を `badge` の実装に置き換え、1ボタン操作を有効にし、
操作表示をSW1に変更しています。スプライトは移植元の生成済みデータを使っています。

The Go gopher was designed by [Renée French](https://reneefrench.blogspot.com/),
licensed under [CC BY 4.0](https://creativecommons.org/licenses/by/4.0/).

TinyGoロゴには[指定された画像](https://encrypted-tbn0.gstatic.com/images?q=tbn:ANd9GcSPeG0euLXxf-9uQ4XR_4dmq32-PiGb-mflkWEAVzMg3Q&s=10)
を使用し、縦横比を保って52×44pxに縮小しています。

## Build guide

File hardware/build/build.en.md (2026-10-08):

## TinyGo Conf 2026 Badge Build Guide

[日本語](build.md)

This guide explains how to assemble the badge board distributed at TinyGo Conference 2026.
The required parts are listed below. Please provide your own soldering iron and other assembly tools.

### Parts

You will need the following parts:

- ESP32-S3 DevKit

https://akizukidenshi.com/catalog/g/g131148/

- Joystick

https://akizukidenshi.com/catalog/g/g115951/

- ST7789 display

https://akizukidenshi.com/catalog/g/g131019/

- One current-limiting resistor

https://akizukidenshi.com/catalog/g/g116332/

- Two key switches

https://shop.yushakobo.jp/collections/all-switches

- Two keycaps

https://shop.yushakobo.jp/collections/keycaps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

- Two switch sockets

https://shop.yushakobo.jp/products/a01ps?variant=37665172521121

- MAX98357A

https://amzn.asia/d/054giKgU

- RGB LEDs (use two from the pack of five)

https://akizukidenshi.com/catalog/g/g115478/

- Infrared receiver module

https://akizukidenshi.com/catalog/g/g131157/

- Infrared LED

https://akizukidenshi.com/catalog/g/g112612/

- AHT21B temperature and humidity sensor

https://akizukidenshi.com/catalog/g/g130222/

- Two 20-pin socket strips

https://akizukidenshi.com/catalog/g/g103077/

- Two 2-pin socket strips

https://akizukidenshi.com/catalog/g/g110097/

### Assembly

#### LEDs / SK6812MINI-E

Start with the LEDs. Turn the board over and solder the surface-mount SK6812 LEDs to the back.

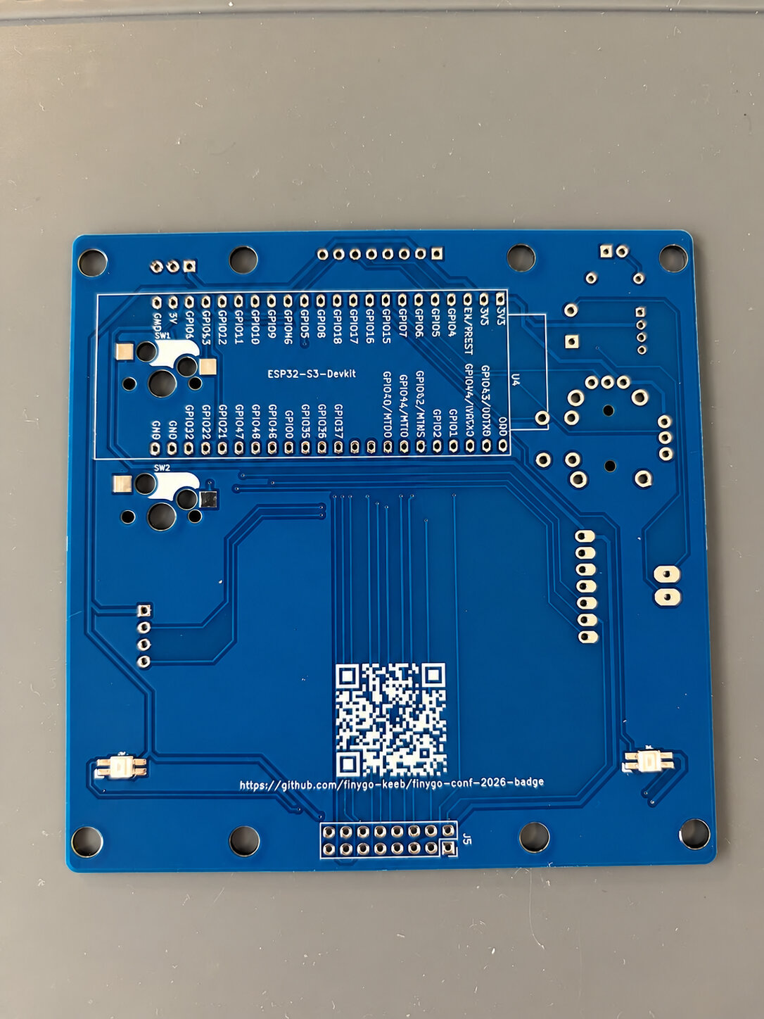
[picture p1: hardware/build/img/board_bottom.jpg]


The SK6812 has a specific orientation. Look closely at the LED and you will see one corner cut at a 45-degree angle.

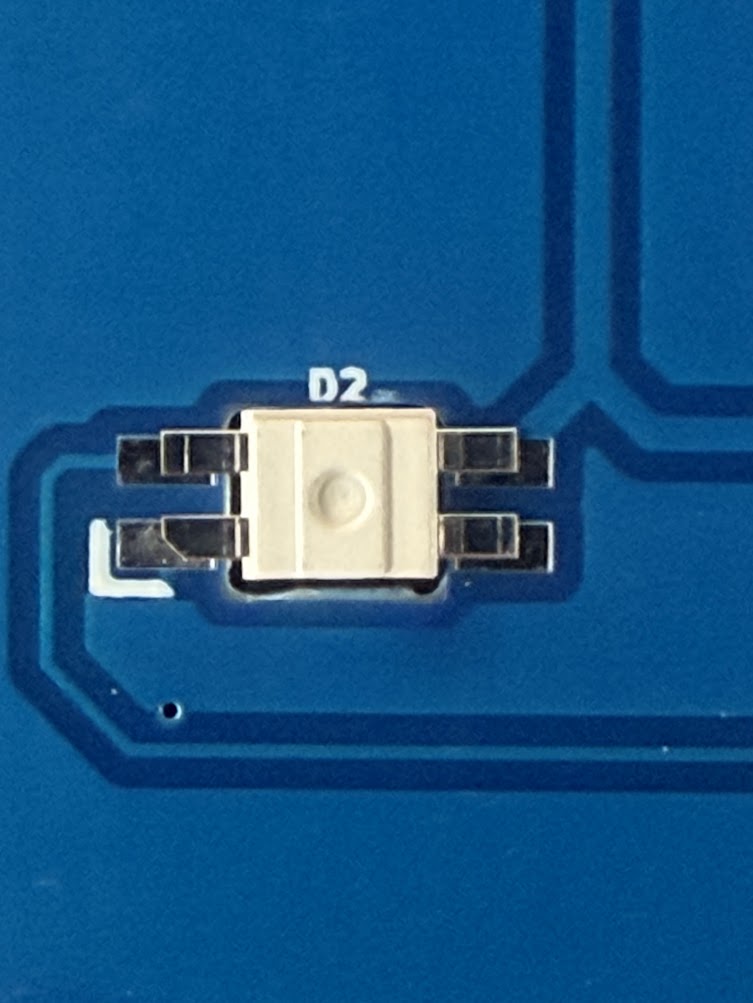
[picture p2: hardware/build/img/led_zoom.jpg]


On the back of the board, a white L-shaped marking shows where each LED belongs.
Align the LED's cut corner with the white L. If either LED faces the wrong way, the LEDs will not light, so check their orientation before soldering.

Place both LEDs in the correct orientation, then solder them.

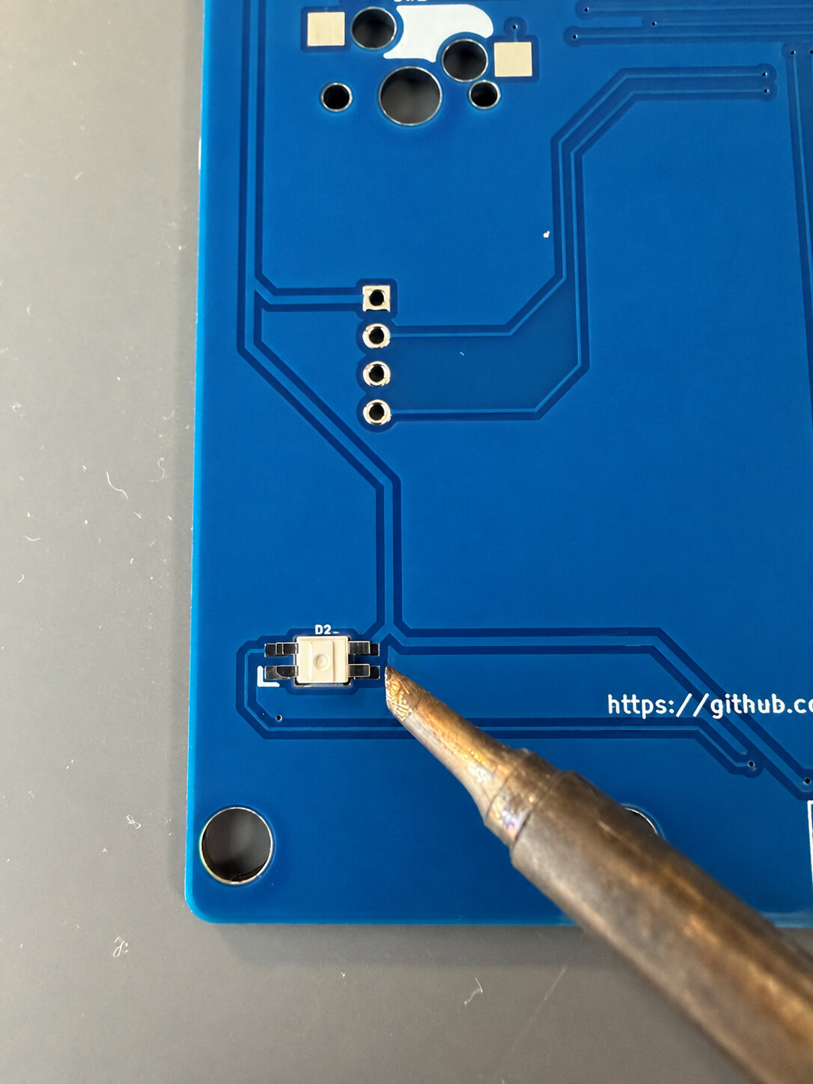
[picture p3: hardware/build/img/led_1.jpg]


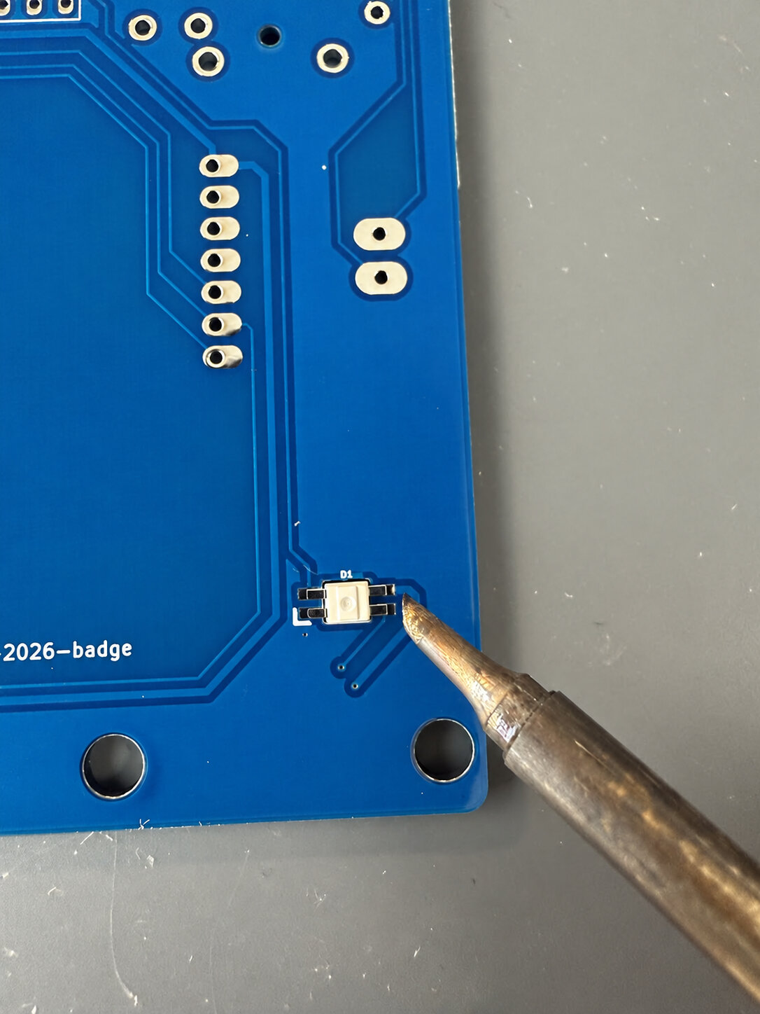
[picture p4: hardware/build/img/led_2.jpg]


Tip: Pre-tinning the pads can make it easier to solder the LEDs, though it is not required.

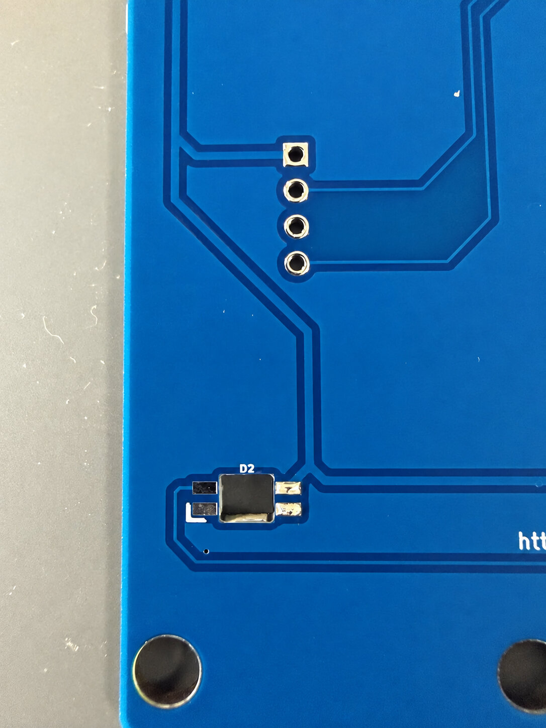
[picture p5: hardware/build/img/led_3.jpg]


Solder all four connections.

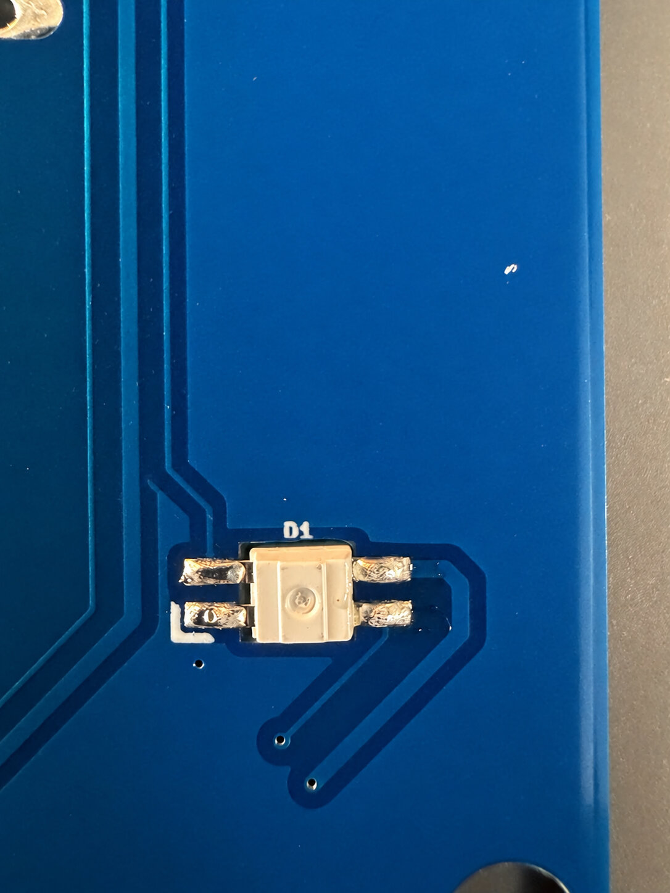
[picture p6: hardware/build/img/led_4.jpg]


#### Switch sockets

Install the switch sockets. Remove them from their packaging and place them on the board according to the silkscreen.

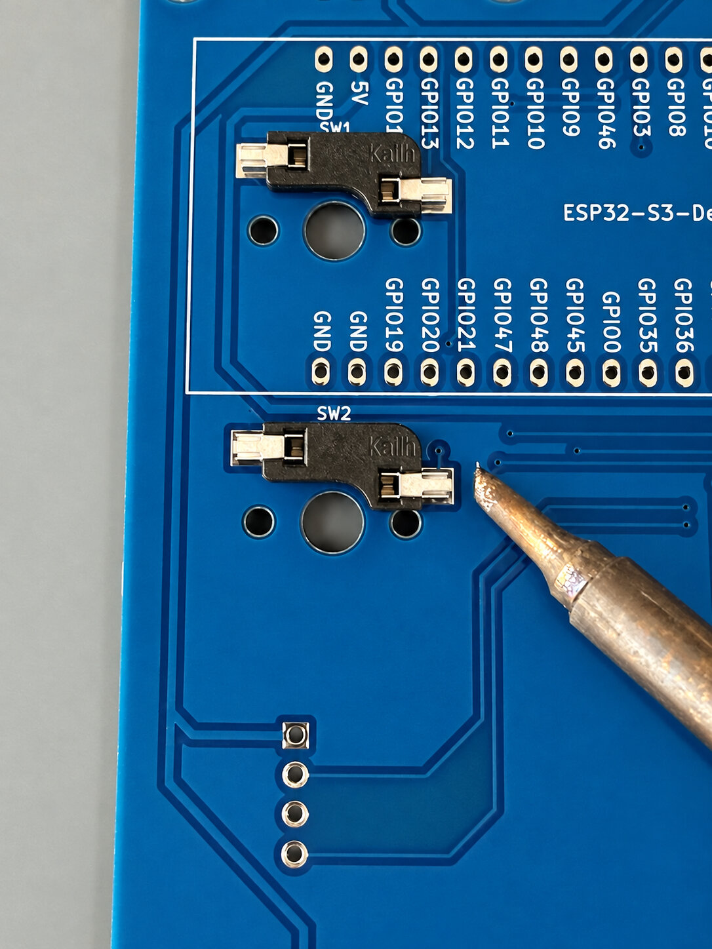
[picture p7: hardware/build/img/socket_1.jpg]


Apply the soldering iron from the side and feed solder into the joint. Check carefully that each socket is soldered to the board.

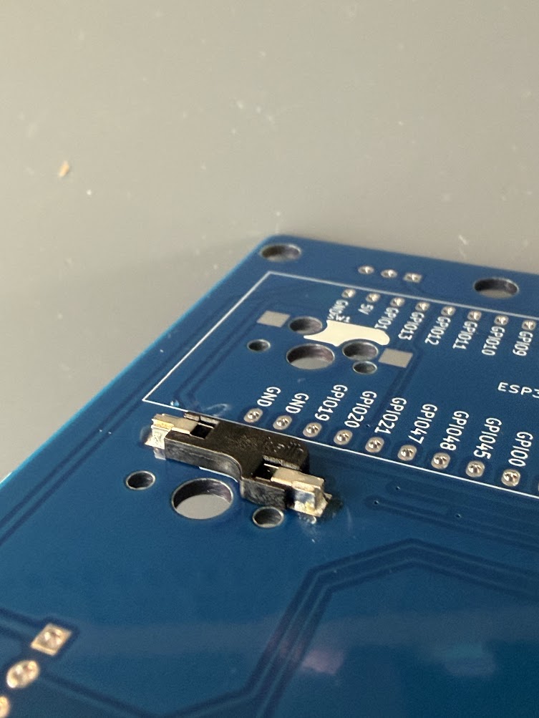
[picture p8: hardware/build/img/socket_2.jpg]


Even if a joint looks soldered from above, a gap between the socket and board when viewed from the side means the solder has not reached the joint. Solder it again.

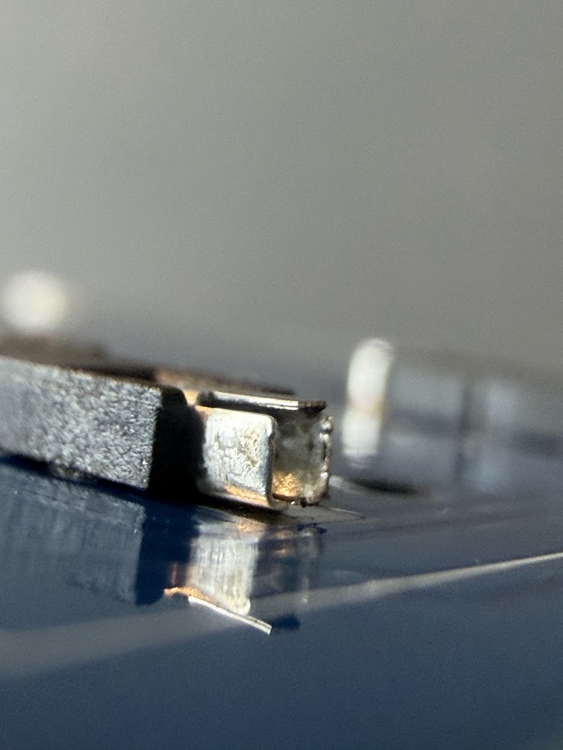
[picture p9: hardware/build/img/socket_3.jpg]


#### Temperature and humidity sensor

Install the temperature and humidity sensor. First, solder its socket pins to the sensor module. If the pins are already soldered, insert the module from the front of the board.

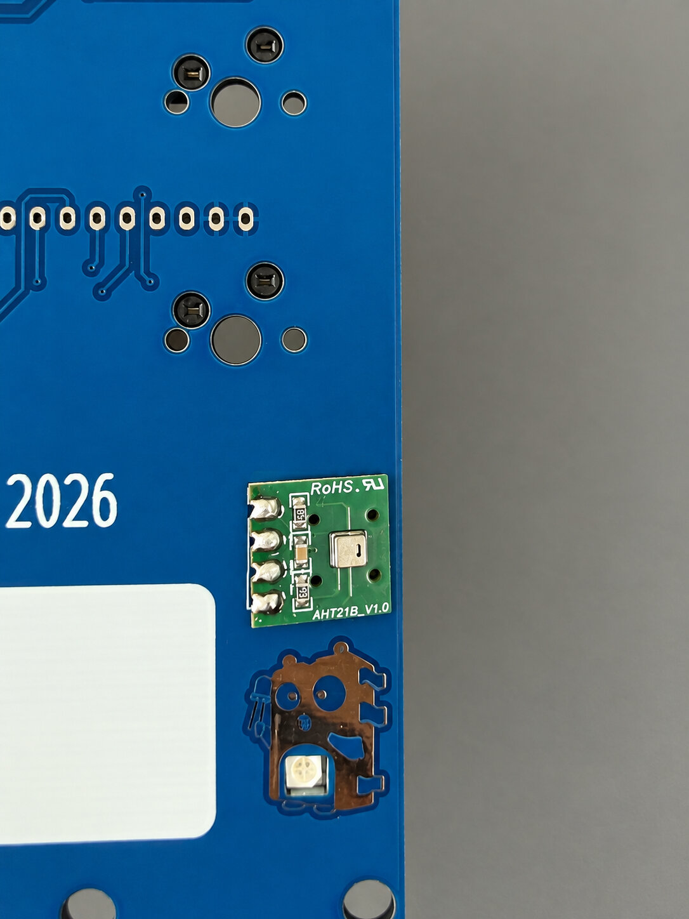
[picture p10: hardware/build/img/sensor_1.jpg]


After inserting the module, turn the board over and solder its pins.

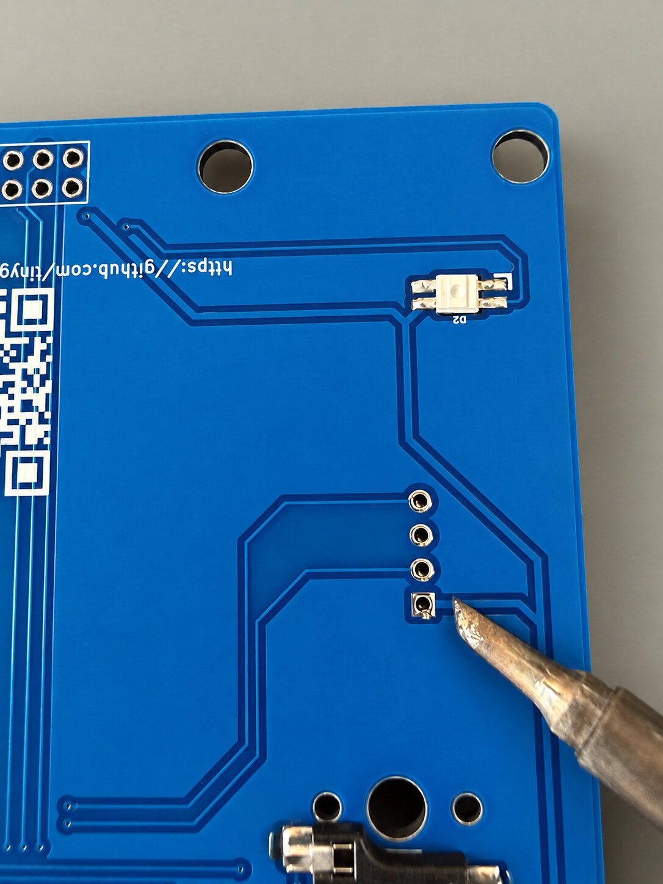
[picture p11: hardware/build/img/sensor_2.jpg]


Solder all four connections.

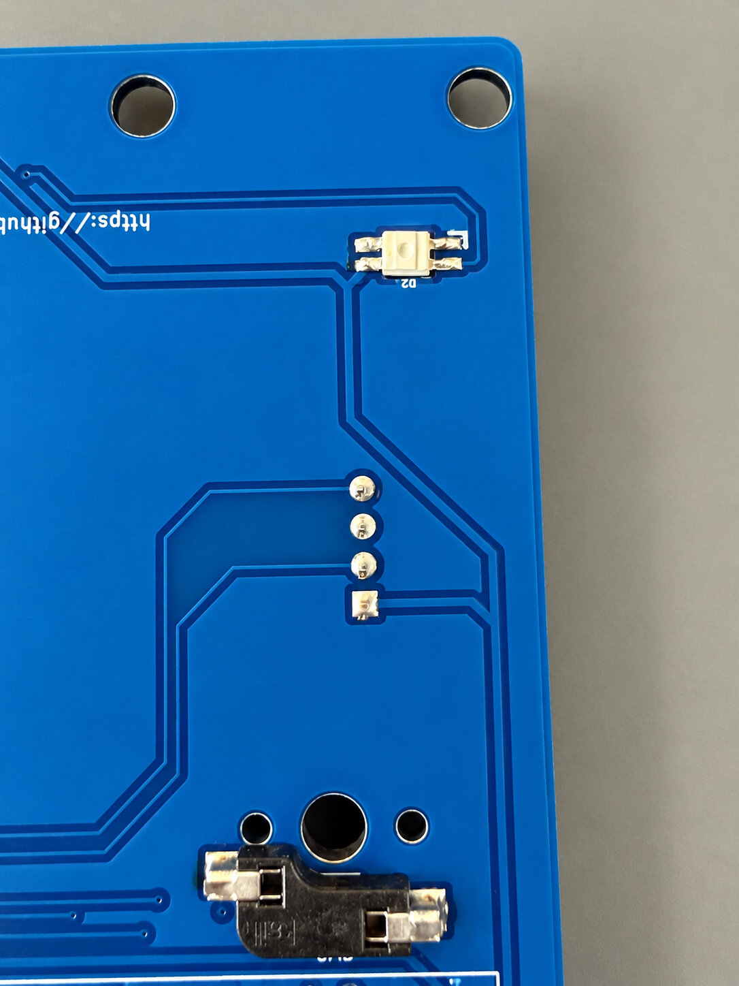
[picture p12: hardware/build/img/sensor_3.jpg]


#### Infrared LED and resistor

Solder the infrared LED and resistor. Start with the resistor.

Bend the resistor leads at their bases into a U shape.

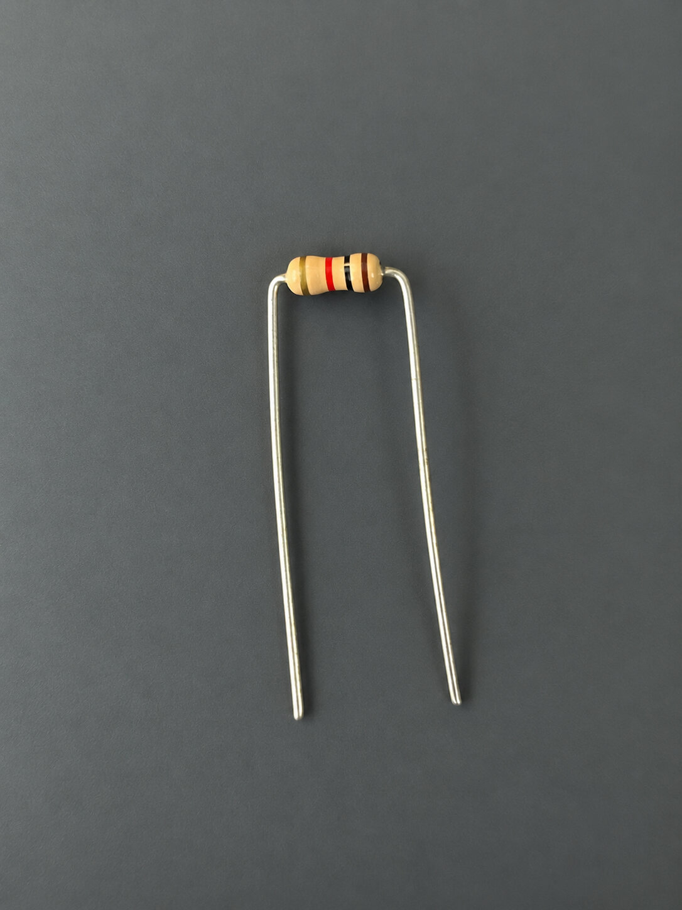
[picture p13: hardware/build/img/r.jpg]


From the front of the board, insert the bent resistor into the two holes above and to the right of the Grove connector. The resistor has no polarity.

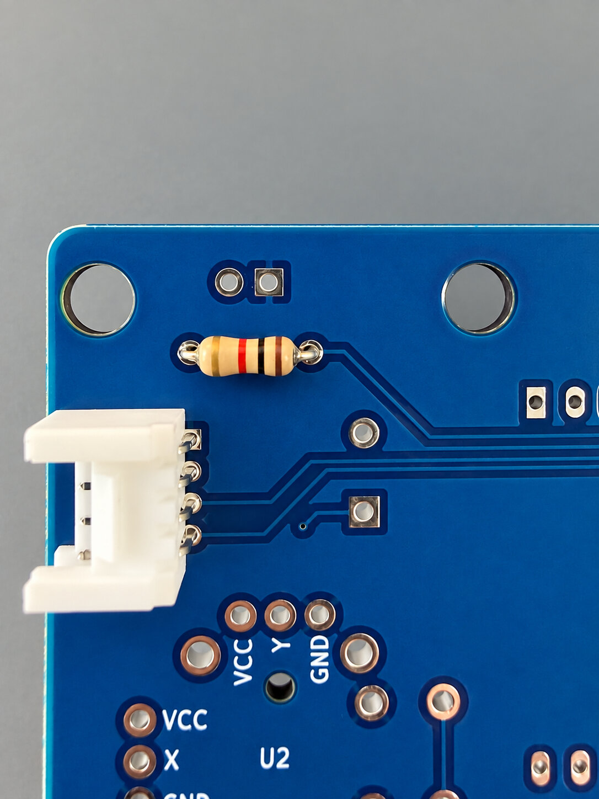
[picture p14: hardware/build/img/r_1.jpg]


Turn the board over and solder the resistor.

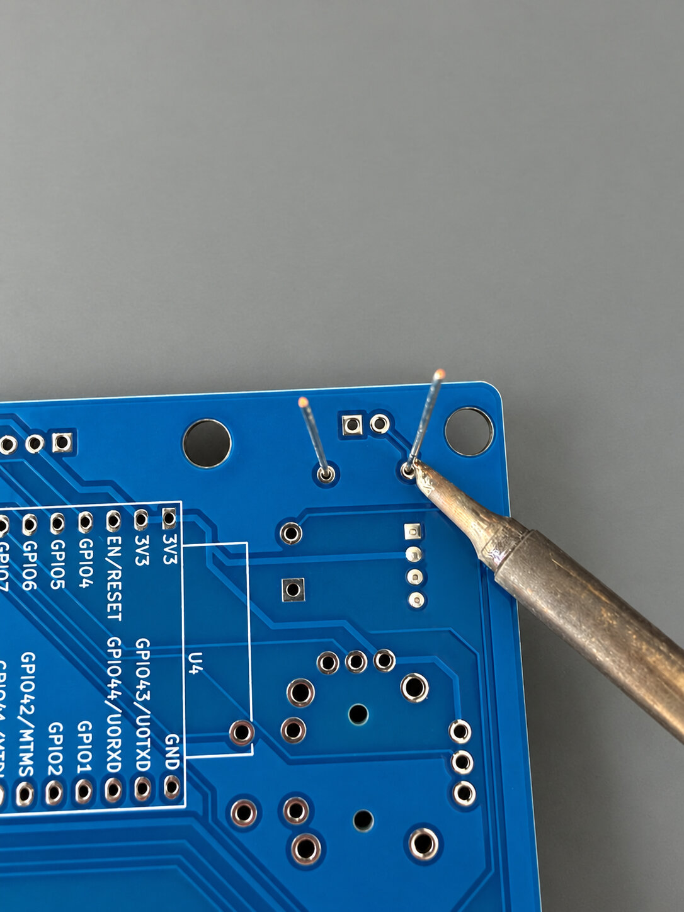
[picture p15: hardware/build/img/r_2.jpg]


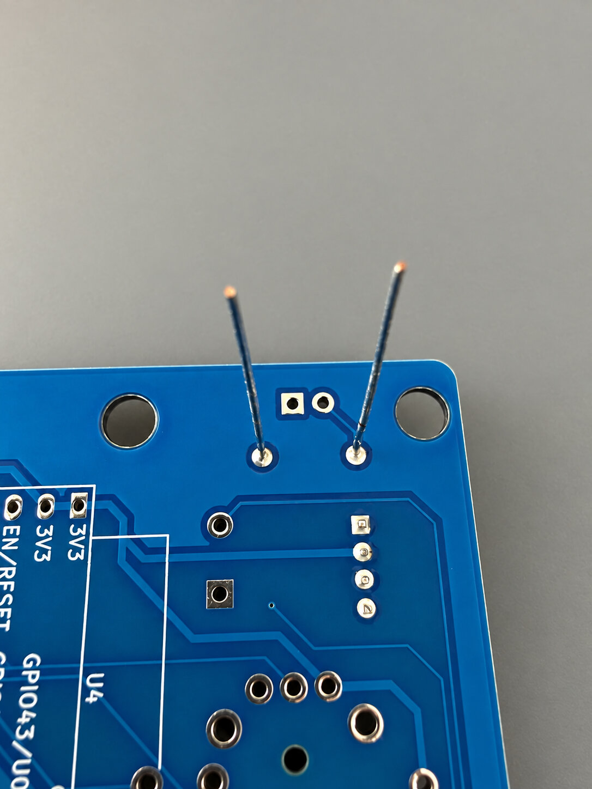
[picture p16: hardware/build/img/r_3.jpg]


Trim the excess leads with side cutters. Hold each lead with your free hand while cutting it so it does not fly toward your eyes or someone nearby.

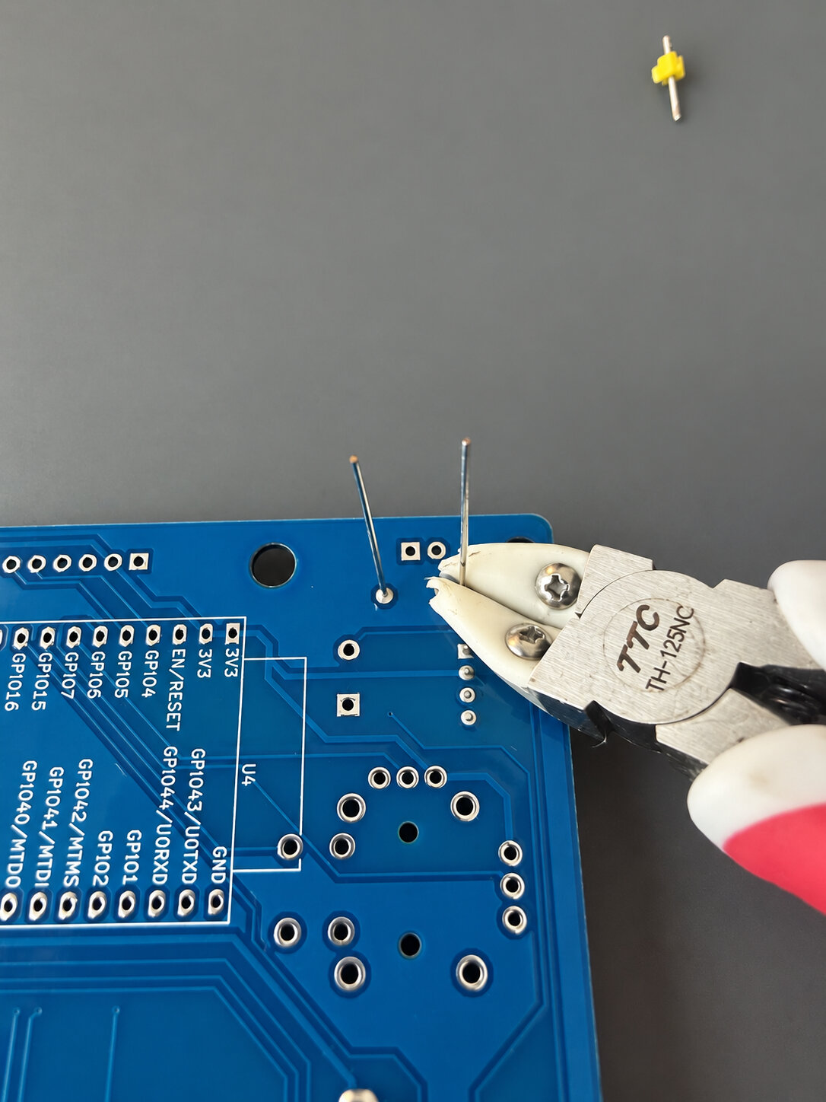
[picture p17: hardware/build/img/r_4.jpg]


Next, solder the infrared LED. It has a specific orientation: the longer lead goes on the left and the shorter lead on the right.

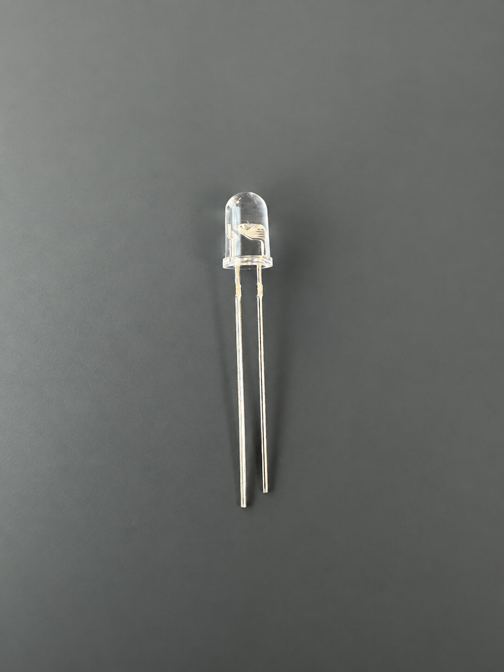
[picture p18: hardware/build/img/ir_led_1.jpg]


Check the orientation and insert the LED from the front of the board.

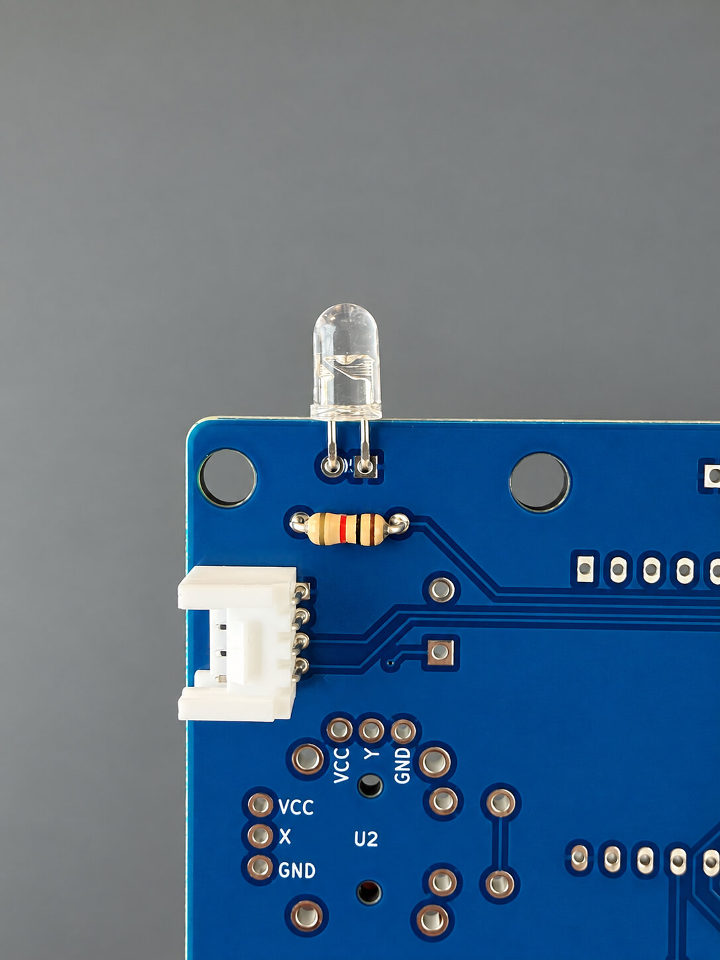
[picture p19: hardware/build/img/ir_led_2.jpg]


Turn the board over and solder it.

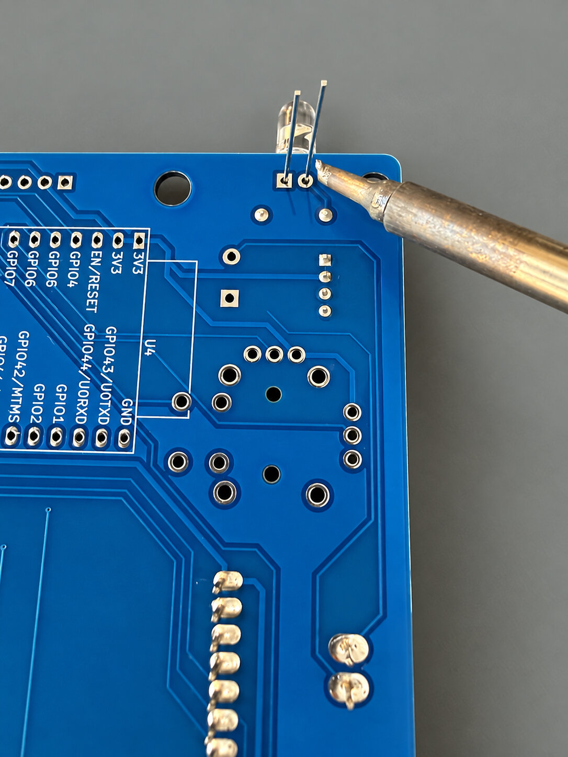
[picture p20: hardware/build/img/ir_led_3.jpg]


Trim the excess leads with side cutters. Keep the trimmed leads; you will use them in a later step.

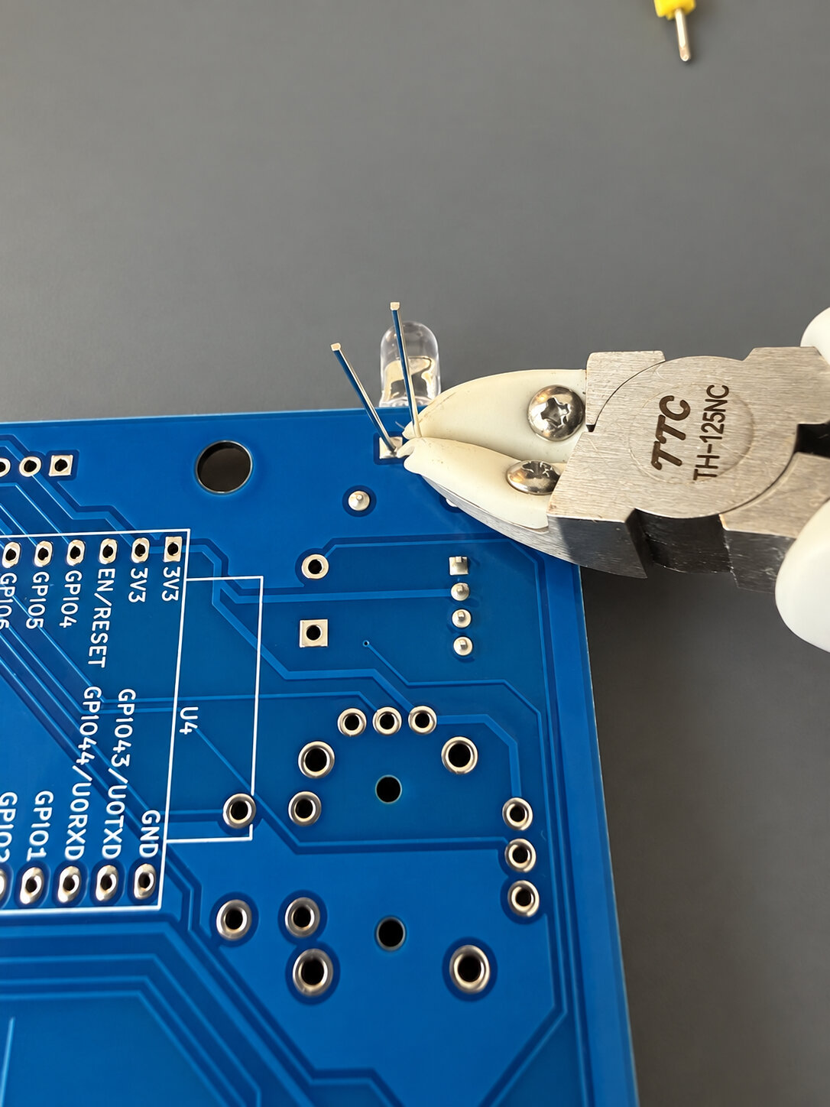
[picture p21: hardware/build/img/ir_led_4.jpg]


#### Audio module

Install the audio module. First, solder the socket pins to the module. If they are already soldered, insert the module from the front of the board.

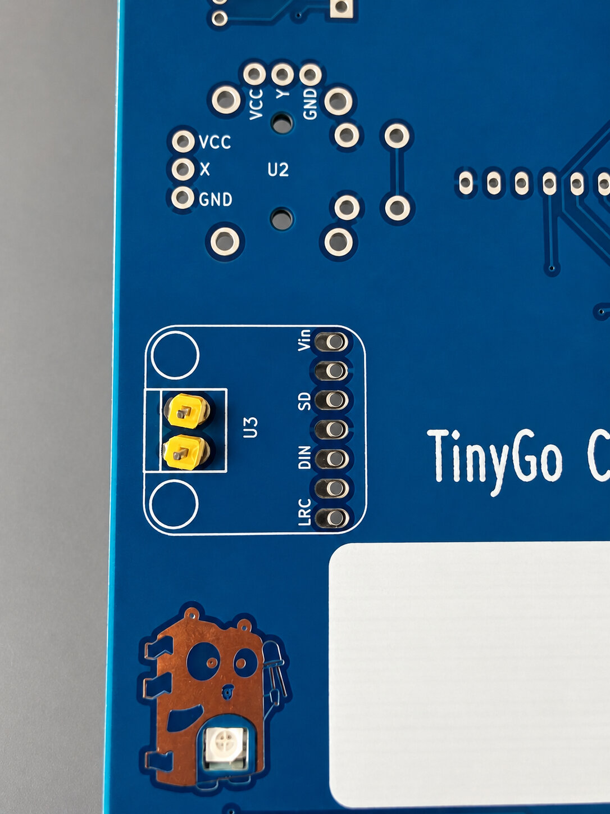
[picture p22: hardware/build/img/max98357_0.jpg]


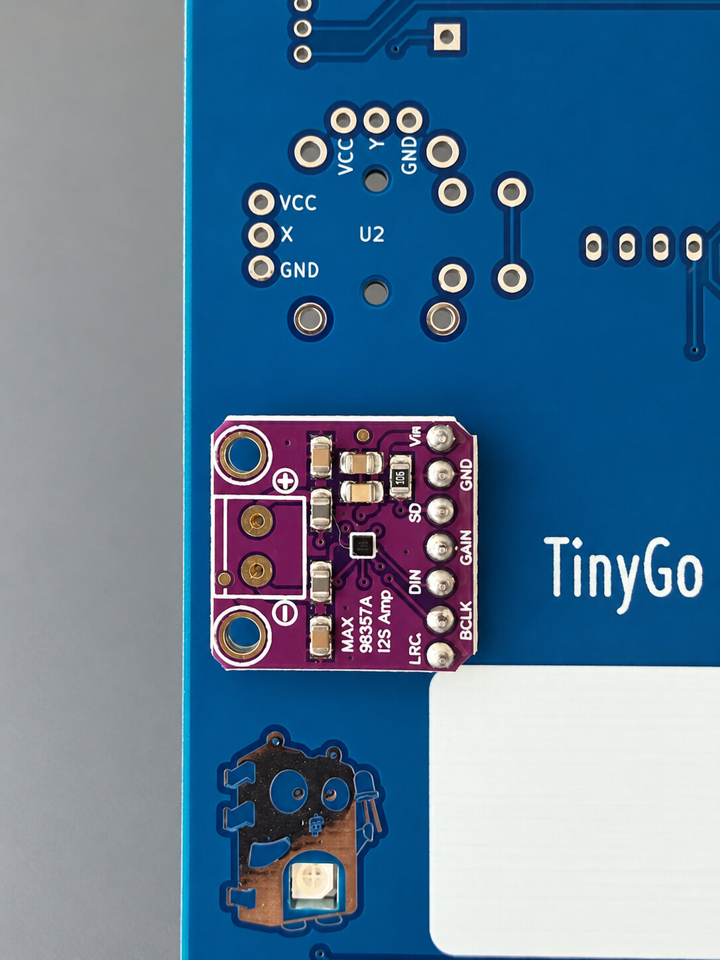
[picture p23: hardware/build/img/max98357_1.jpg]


Turn the board over and solder the pins.

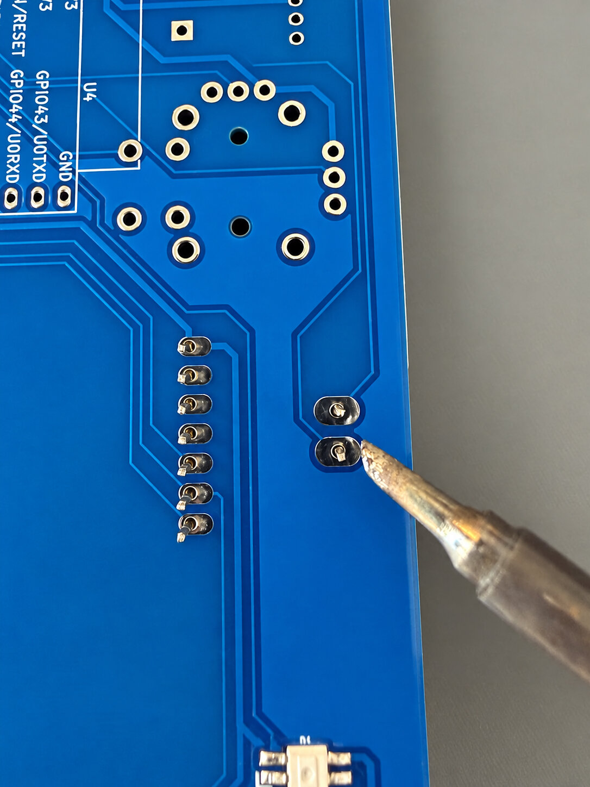
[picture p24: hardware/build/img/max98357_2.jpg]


The pins on the back are now soldered.

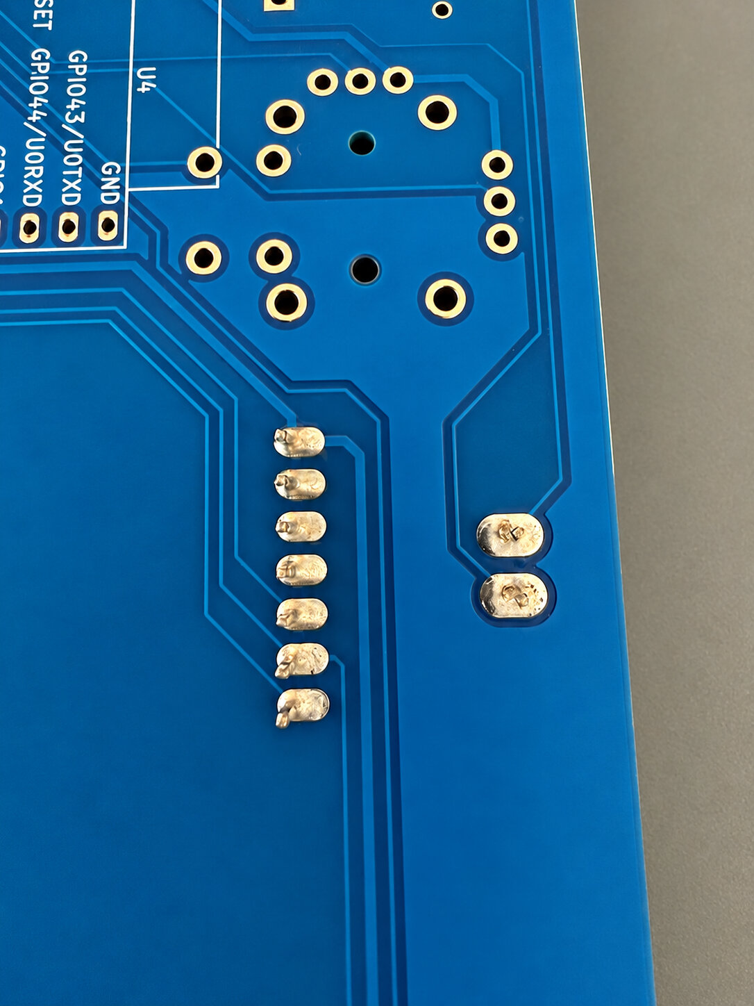
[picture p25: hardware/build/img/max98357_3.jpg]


Turn the board back over and solder the pin header on the left.

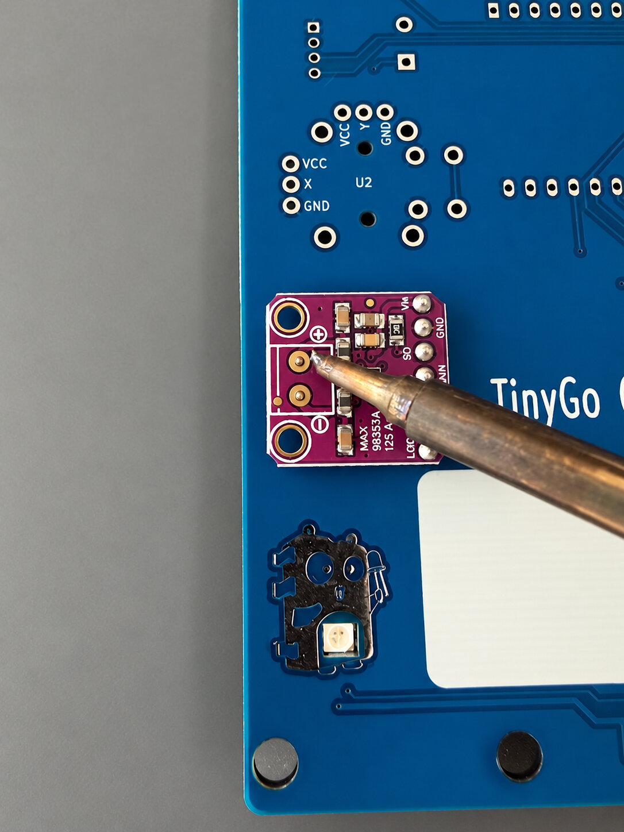
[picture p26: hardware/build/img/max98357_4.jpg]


After soldering the pin headers on both sides, turn the board over and cut off all protruding, unused header pins.

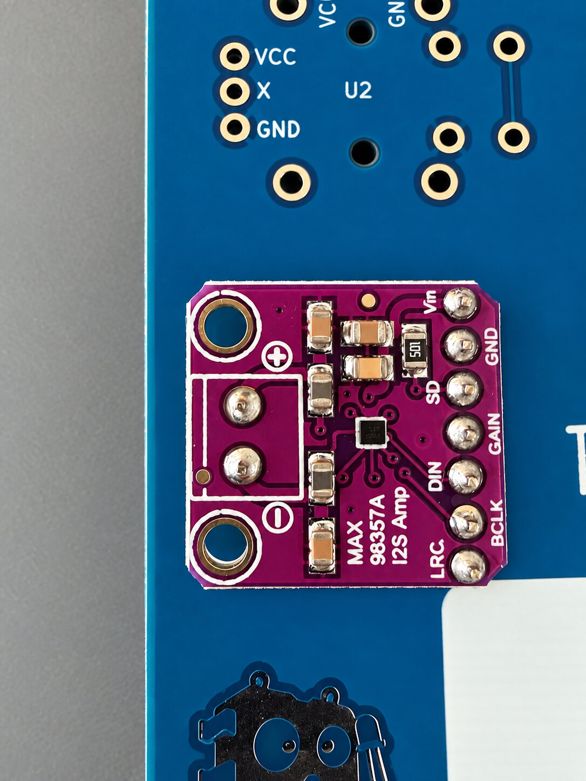
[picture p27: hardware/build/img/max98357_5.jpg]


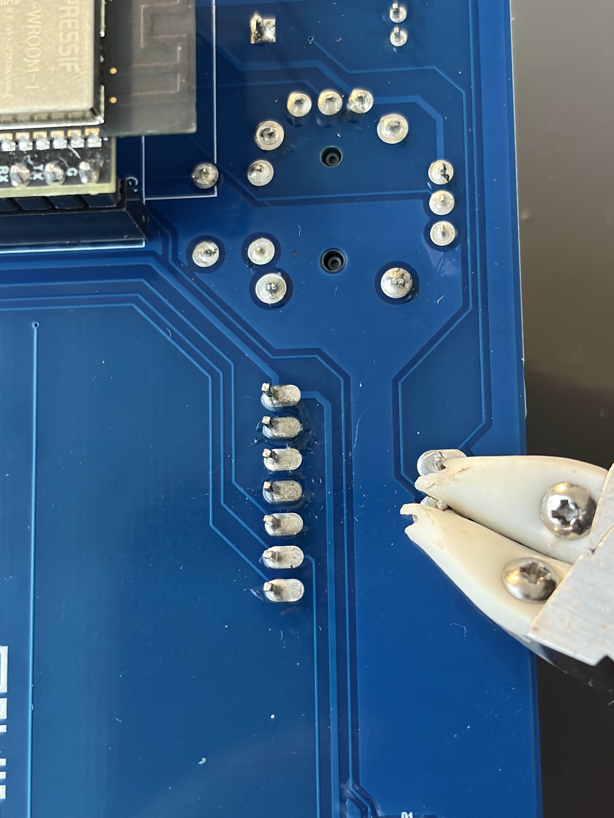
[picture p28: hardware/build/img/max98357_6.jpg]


Bend the lead saved from the resistor into a U shape.

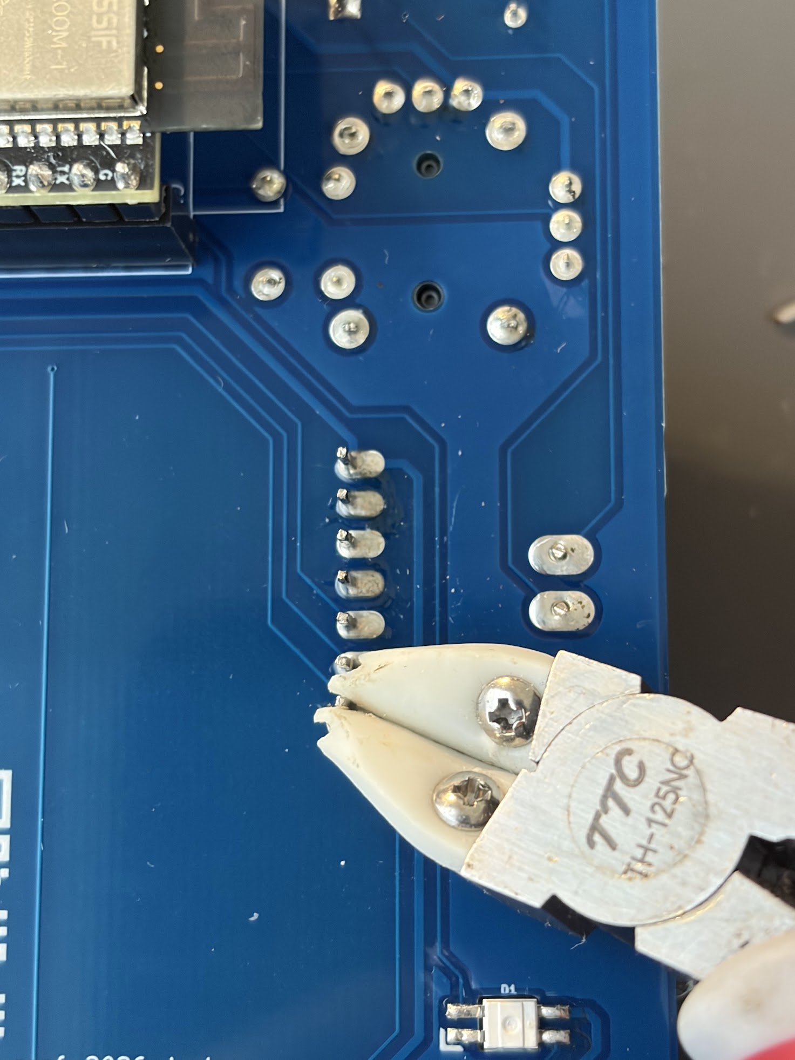
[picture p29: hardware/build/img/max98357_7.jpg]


Place it across the second and fourth pins from the top and solder it in place.

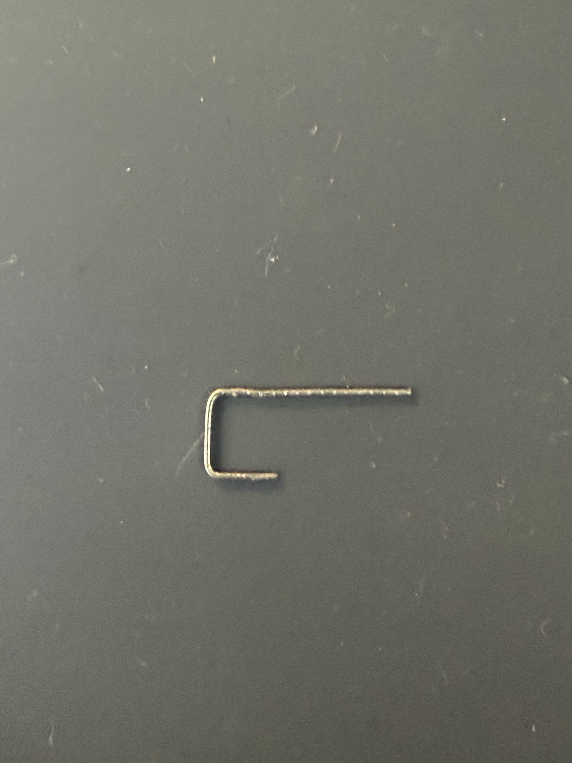
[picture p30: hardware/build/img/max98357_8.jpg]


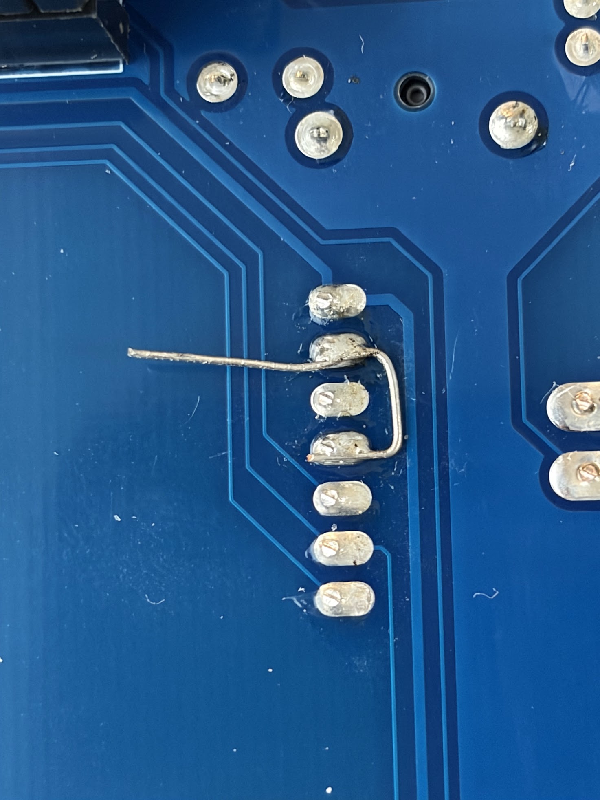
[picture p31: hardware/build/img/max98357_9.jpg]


#### Grove connector

Insert the Grove connector from the front of the board.

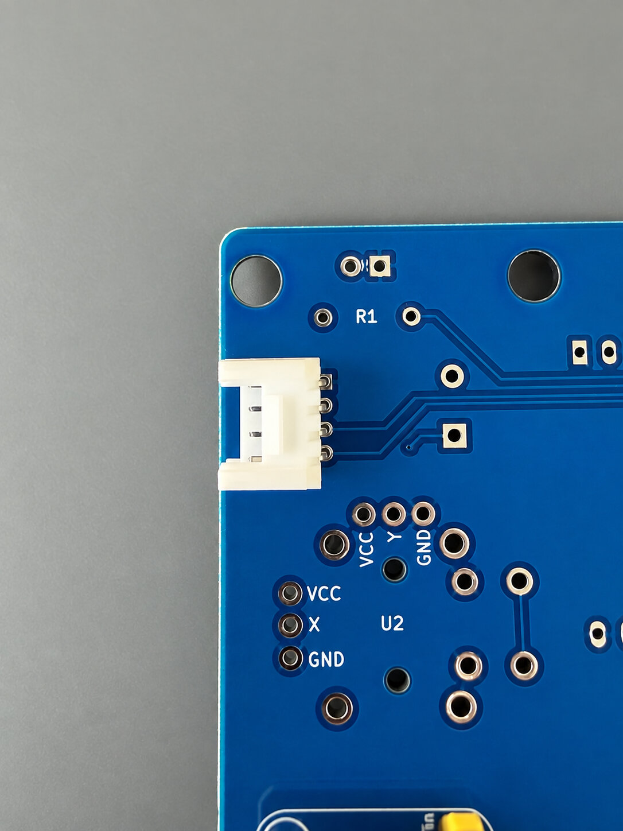
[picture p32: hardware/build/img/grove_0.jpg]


Turn the board over and solder the connector.



Solder all four connections.



#### Infrared receiver module

Install the infrared receiver module.

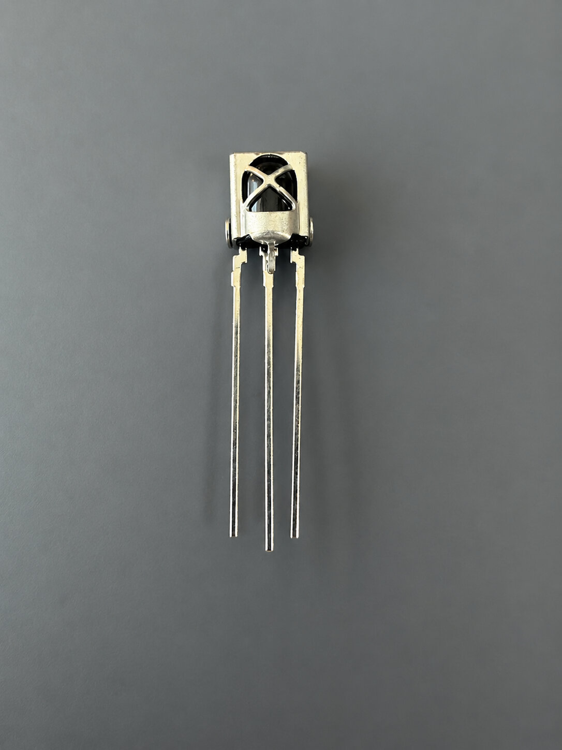
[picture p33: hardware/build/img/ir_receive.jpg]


Insert it from the front of the board. The rounded, protruding receiver should face outward, away from the board.

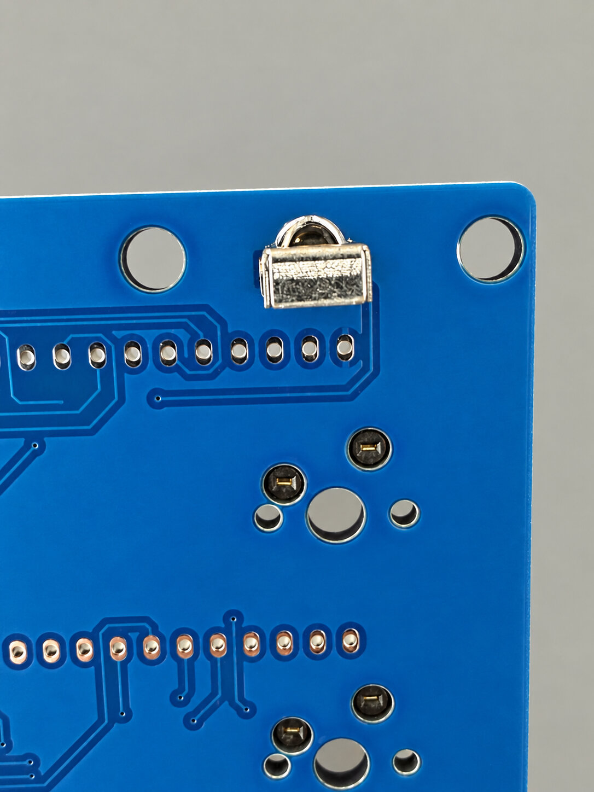
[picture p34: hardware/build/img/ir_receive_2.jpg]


Turn the board over and solder it.

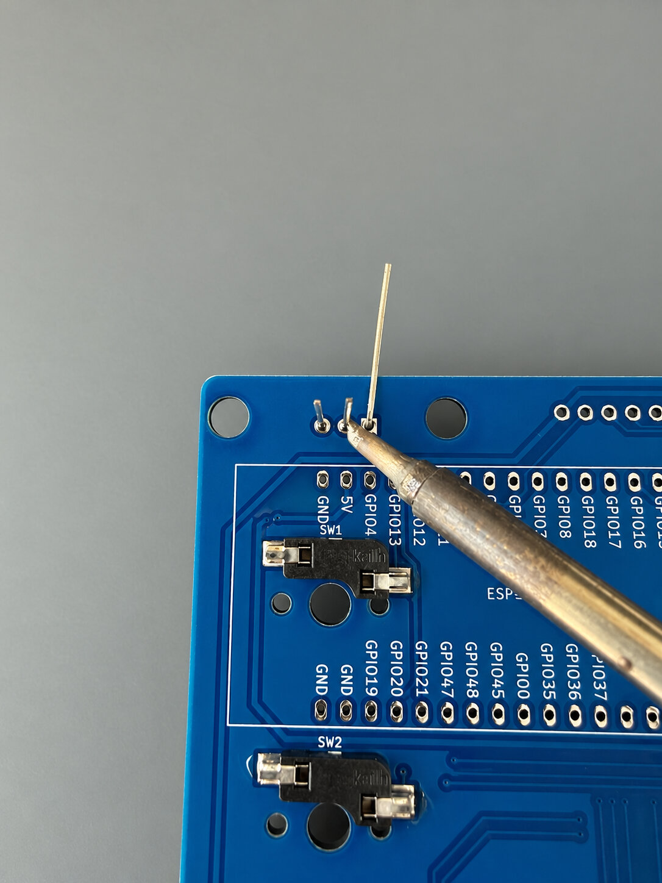
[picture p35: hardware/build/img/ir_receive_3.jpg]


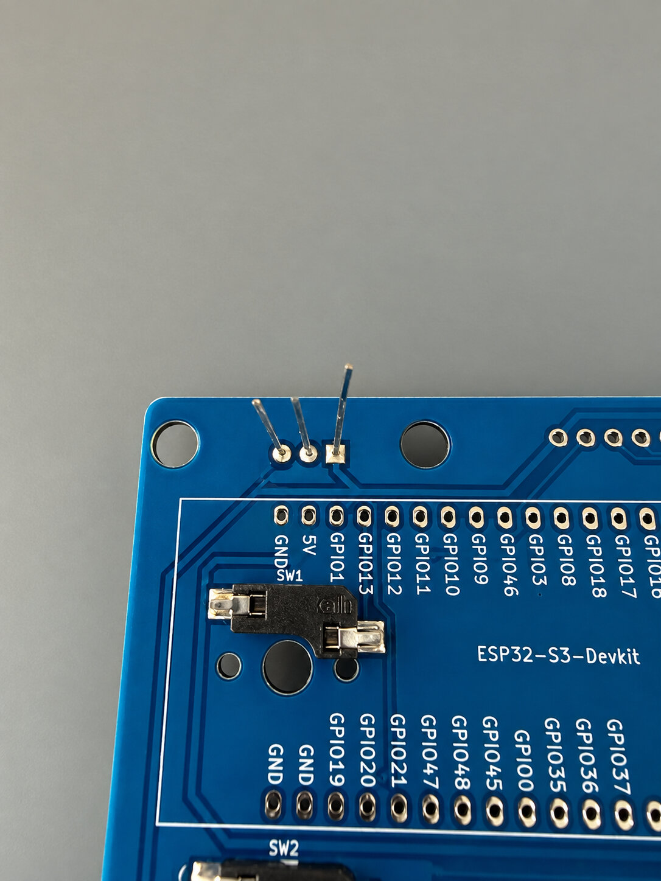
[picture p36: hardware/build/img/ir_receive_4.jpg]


Trim the excess leads with side cutters.

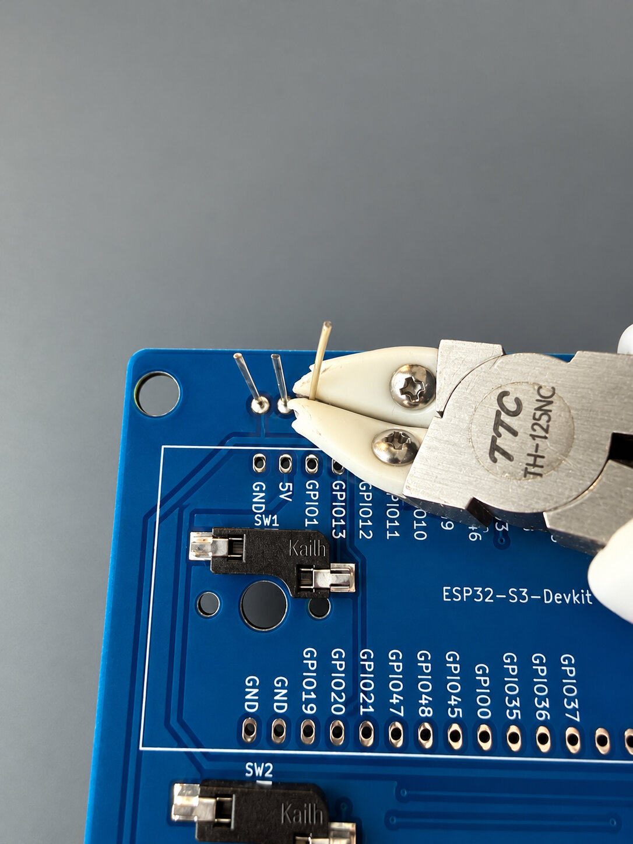
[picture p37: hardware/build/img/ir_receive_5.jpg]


#### Speaker

Insert the speaker from the front of the board, with its + mark facing up.

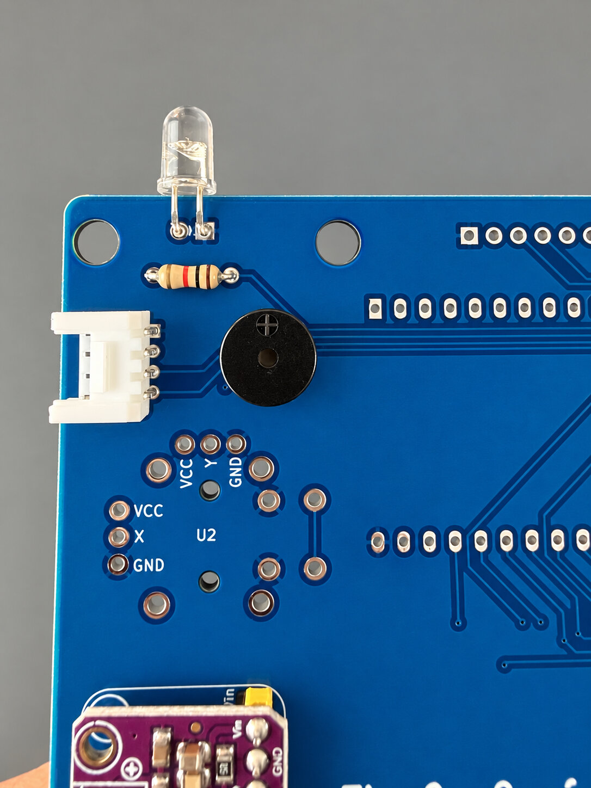
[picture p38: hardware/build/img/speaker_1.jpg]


Turn the board over and solder it.

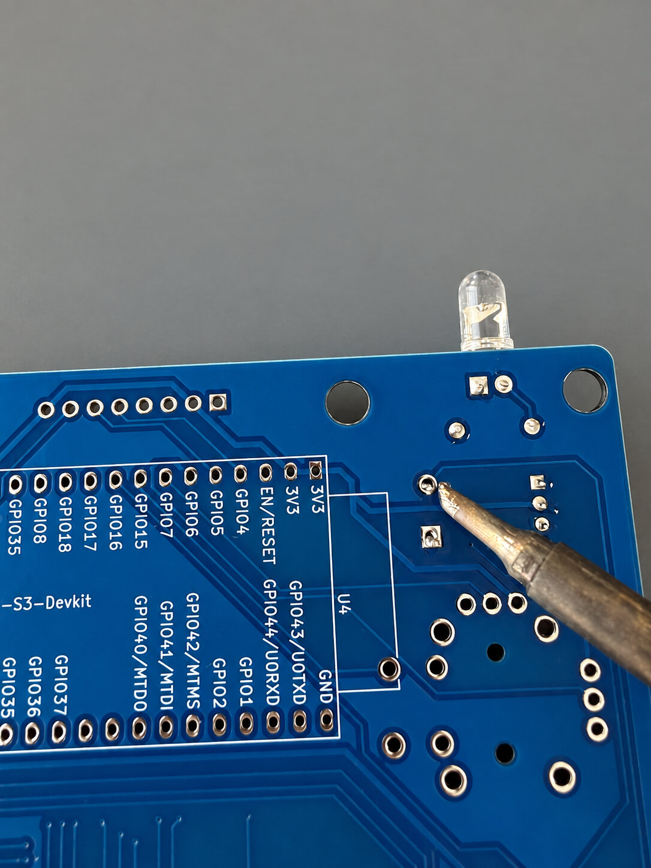
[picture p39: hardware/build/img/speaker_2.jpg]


#### Joystick

Insert the joystick from the front of the board.

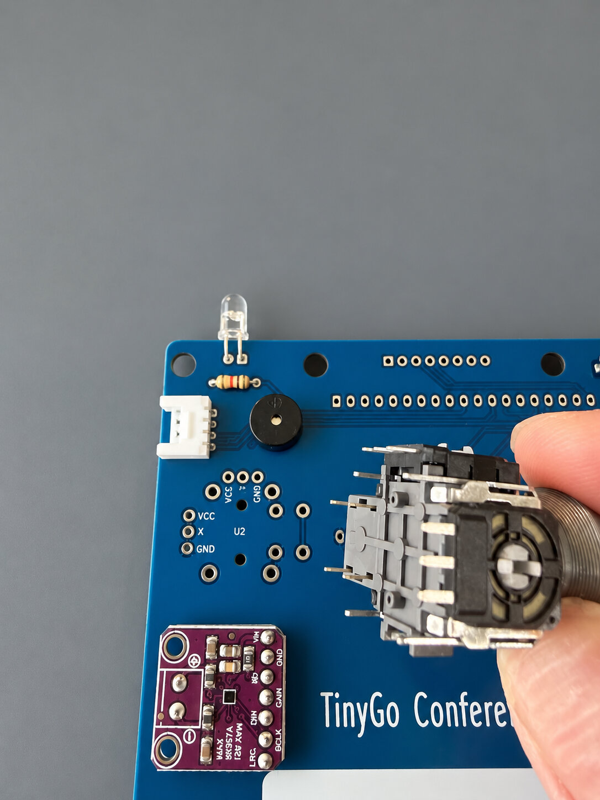
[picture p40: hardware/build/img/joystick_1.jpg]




Turn the board over and solder it.





#### ESP32-S3 DevKit

Solder the socket strips that will mount the ESP32-S3 DevKit to the board.



Fit the 20-pin and 2-pin socket strips onto the DevKit's pin headers.



Check from the side that the sockets are fully seated and level.



With the sockets fitted on both sides of the DevKit, insert the assembly from the back of the badge board.



With the DevKit inserted from the back, solder the socket pins from the front of the badge board.



Solder every pin.



#### Display

First, solder a pin header to the display.



Insert the header and display into a breadboard to hold them in place while soldering. If you do not have a breadboard, insert the header into the badge board and solder it there instead.



After soldering the header to the display, insert it from the front of the badge board.

Use tape to hold the display in place and keep it level. Check its position from the side. Once it is secure and level, turn the board over and solder it.



All soldering is complete.

#### Functional test

Check that the assembled parts work properly. Badges distributed at the workshop already have the `selftest` program flashed. Power the badge on and run the test.

If you assembled the badge yourself, flash the test program with:

```
cd firmware
tinygo flash --target esp32s3-box-3 --size short ./examples/selftest
```

If everything works, the display shows ALL OK as in the photo below.



#### Case

Install the case. If you do not have one, print a case with a 3D printer.

Align the case, which is the same size as the board, with the holes at the board's corners.





Put the key switches into the case and insert them into the board from the front.





Finally, attach four clips at the corners so the board cannot come loose from the case.



The badge is complete. Great work!



#### Optional expansion

You can fit a 2x8 socket strip into the holes at the bottom of the board. A mini breadboard fits in the blank name area in the center, making it easy to experiment with electronics.

https://akizukidenshi.com/catalog/g/g102761/

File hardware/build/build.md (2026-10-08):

## TinyGo Conf 2026 Badge のビルドガイド

[English](build.en.md)

このドキュメントではTinyGo Conference 2026で配布された基板の組み立て方を説明します。  
必要なパーツは以下に記載しますが、はんだごてなど組み立てに必要な道具はご自分で用意してください。

### パーツ

組み立てには以下の部品が必要になります。

- ESP32 S3 Devkit

https://akizukidenshi.com/catalog/g/g131148/

- ジョイスティック

https://akizukidenshi.com/catalog/g/g115951/

- ST7789液晶

https://akizukidenshi.com/catalog/g/g131019/

- 電流制限抵抗 1つ

https://akizukidenshi.com/catalog/g/g116332/

- キースイッチ 2つ

https://shop.yushakobo.jp/collections/all-switches

- キーキャップ 2つ

https://shop.yushakobo.jp/collections/keycaps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

- キーソケット 2つ

https://shop.yushakobo.jp/products/a01ps?variant=37665172521121

- MAX98357A

https://amzn.asia/d/054giKgU

- RGB LED（5個入りのうち2個使用します

https://akizukidenshi.com/catalog/g/g115478/

- 赤外線受信モジュール

https://akizukidenshi.com/catalog/g/g131157/

- 赤外線LED

https://akizukidenshi.com/catalog/g/g112612/

- 温湿度センサー AHT21B

https://akizukidenshi.com/catalog/g/g130222/

- ピンソケット 20p 2つ

https://akizukidenshi.com/catalog/g/g103077/

- ピンソケット 2p 2つ

https://akizukidenshi.com/catalog/g/g110097/

### 組み立て

#### LED / SK6812MINI-E

最初はLEDを付けます。基板を裏返して表面実装のSK6812をはんだ付けします。  



SK6812には向きがあります。  
LEDををよく見ると斜め45度に切れているのがわかります。



裏返した基板を見ると白い線でL字が入っている箇所があります。  
この白いLと斜め45度に切れているLEDの足を合わせるようにして置いてください。  
1つでも向きを間違うとLEDが光らないので、はんだ付けをする前によく確認してください。

正しい向きでLEDを2個並べたらはんだ付けをしていきます。





※Tipsとして必須ではありませんが、予備はんだをしてLEDをはんだ付けするとうまくいくと思います。



4箇所はんだ付けしてください。



#### スイッチソケット

スイッチソケットを取り付けます。
パーツをパッケージから取り出して、シルクに合わせてスイッチソケットを基板に載せます。



はんだごてを横から当てて、はんだを流し込みます。  
よく確認してスイッチソケットと基板がはんだ付けされているかを確認してください。



はんだ付けしたと思っても、このように横から見ると基板とすきまがあり、はんだが流れていない場合ははんだ付けできていません。  
もう一度はんだ付けをしてください。



#### 温湿度センサー

温湿度センサーを取り付けます。
まず温湿度センサーにピンソケットをはんだ付けします。  
すでにピンソケットがはんだ付けされていれば、基板の表面から温湿度センサーを挿してください。



温湿度センサーを挿したら、基板を裏返してはんだ付けをしてください。



4箇所はんだ付けをしてください。



#### 赤外線LEDと抵抗

赤外線LEDと抵抗をはんだ付けします。  
まず抵抗をはんだ付けします。

抵抗を根元から折り曲げて、コの字にしてください。



折り曲げた抵抗を表面からGroveコネクタの右上の2つの穴に挿します。  
抵抗に向きはありません。



基板を裏返してはんだ付けをしてください。





抵抗をはんだ付けしたら、ニッパーで余分な線をカットしてください。  
ニッパーで線を切るときは、周りや目に飛ばないよう、空いている手で線を持って切ってください。



赤外線LEDをはんだ付けします。
LEDには向きがあります。  
足が長い方を左に、短い方を右に向けるようにしてください。



LEDの向きを確認して基板の表面からLEDを挿します。



LEDを挿したら、基板を裏返してはんだ付けをします。



はんだ付けが終わったら、ニッパーで余分な線をカットします。
余分な線は次の工程で使うので、まだ捨てないでください。



#### オーディオモジュール

オーディオモジュールをはんだ付けします。
まずオーディオモジュールにピンソケットをはんだ付けします。  
すでにピンソケットがはんだ付けされていれば、基板の表面からオーディオモジュールを挿してください。





オーディオモジュールを挿したら、基板を裏返してはんだ付けをしてください。



裏面のはんだ付けがおわりました。



表面に戻して左側のピンヘッダーをはんだ付けしてください。



表面と裏面のピンヘッダーをはんだ付けしたら、基板を裏返します。  
突き出た不要なピンヘッダーを全てカットします。





抵抗をはんだ付けしたときに取っておいたリード線をコの字にまげます。  



リード線を上から2本目と4本目に当てて、はんだ付けをします。  





#### Groveコネクタ

Groveコネクタをはんだ付けします。
基板の表面からGroveコネクタを挿します。



Groveコネクタを挿したら、基板を裏返してはんだ付けをしてください。



4箇所はんだ付けをしたら終了です。



#### 赤外線受信モジュール

赤外線受信モジュールをはんだ付けします。



基板の表面から赤外線受信モジュールを挿します。  
丸く膨らんでいる受信部分が、基板の外を向くようにしてください。



基板を裏返してはんだ付けをします。





はんだ付けが終わったら、ニッパーで余分な線をカットします。



#### スピーカー

スピーカーをはんだ付けします。
基板の表面からスピーカーを挿します。  
この時スピーカーの＋のマークを上にして挿してください。



基板を裏返してはんだ付けをします。



#### ジョイスティック

基板の表面からジョイスティックを挿します。





基板を裏返してはんだ付けをします。





#### ESP32 S3 Devkit

ESP32 S3 Devkit を基板に取り付けるピンソケットをはんだ付けします。



ESP32 S3 Devkitのピンヘッダーに20Pinと2Pinのピンソケットを挿します。 



横から見て奥までピンソケットが入っていて、水平であることを確認してください。



ESP32 S3 Devkitの両サイドにピンソケットを挿したら、基板の裏面から挿します。



Devkitを裏面で挿したら、基板の表面からはんだ付けをします。



すべてはんだ付けしてください。



#### 液晶

基板に液晶をはんだ付けします。
まず液晶にピンヘッダーをはんだ付けします。



ブレットボードにピンヘッダーと液晶を挿して固定したら、はんだ付けしてください。  
ブレットボードがない場合は、ピンヘッダーを基板に挿してはんだ付けしてください。



液晶にピンヘッダーをはんだ付けしたら、基板の表面から挿します。

うまく液晶を水平に取り付けるために、テープを利用して固定してください。  
テープで固定したら横から見て、液晶が水平であることを確認します。  
液晶の固定が問題なければ、基板を裏返してはんだ付けをします。  



はんだ付けは以上で終了です。お疲れ様でした。

#### 動作確認

正常にパーツを取り付けられているか動作確認をします。  
ワークショップでは動作確認用の `selftest` プログラムが書き込まれています。　　
電源を入れて動作確認をしてください。

ご自分で組み立てられた方は、以下のコマンドでプログラムを書き込んでください。

```
cd firmware
tinygo flash --target esp32s3-box-3 --size short ./examples/selftest
```

動作が全て正常であれば、以下の写真のようにALL OKと液晶画面に表示されます。



#### ケース

ケースを取り付けます。
※ケースがない場合は、以下のファイルを3Dプリンターで印刷してください。

基板と同じ大きさのケースを基板の角の穴に合わせてはめます。





キースイッチをケースに入れて基板に表面から挿します。





最後にケースから基板が外れないように、クリップを角に４つ付けます。



これで完成です。
お疲れ様でした。



#### おまけ

基板の下の穴に2x8のピンソケットを挿すことができます。
真ん中の名前を書くスペースにミニブレットボードを置くことで、簡単に電子工作も楽しめます。

https://akizukidenshi.com/catalog/g/g102761/

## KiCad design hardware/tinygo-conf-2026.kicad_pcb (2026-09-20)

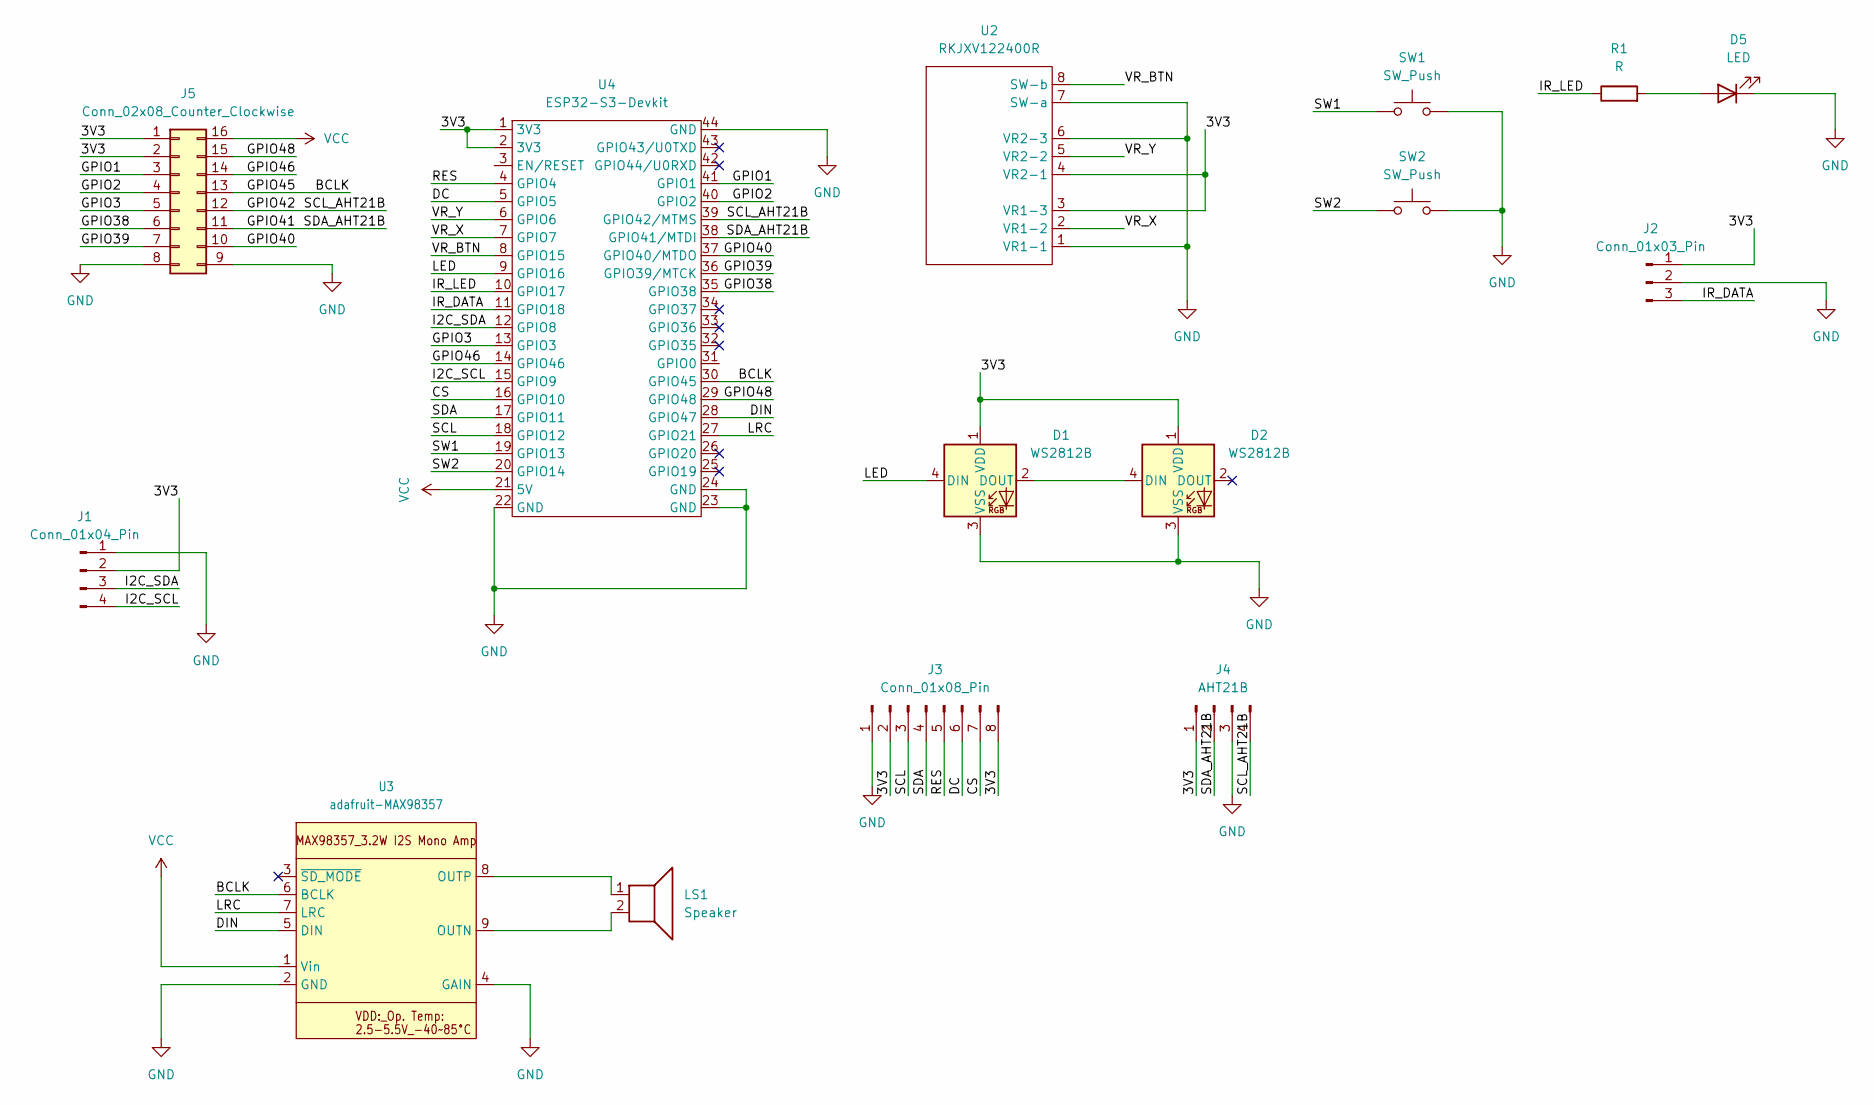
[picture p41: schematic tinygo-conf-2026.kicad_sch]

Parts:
D1, D2: WS2812B; YS-SK6812MINI-E
D5: LED; LED_D3.0mm_Clear
J1: Conn_01x04_Pin; PinHeader_1x04_P2.00mm_Vertical
J2: Conn_01x03_Pin; PinHeader_1x03_P2.54mm_Vertical
J3: Conn_01x08_Pin; ST7789_1.3_240x240_LCD_Module
J4: AHT21B; PinHeader_1x04_P2.54mm_Vertical
J5: Conn_02x08_Counter_Clockwise; PinSocket_2x08_P2.54mm_Vertical
LS1: Speaker; Buzzer_TDK_PS1240P02BT_D12.2mm_H6.5mm
R1: R; R_Axial_DIN0207_L6.3mm_D2.5mm_P7.62mm_Horizontal
SW1, SW2: SW_Push; keyswitch_cherrymx_hotswap_1u
U2: RKJXV122400R
U3: adafruit-MAX98357
U4: ESP32-S3-Devkit; ESP32-S3-DevKitC

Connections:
/3V3: D1.1 (VDD), D2.1 (VDD), J1.2, J2.1, J3.2, J3.8, J4.1, J5.1, J5.2, U2.3 (VR1-3), U2.4 (VR2-1), U4.1 (3V3), U4.2 (3V3)
/BCLK: J5.13, U3.6 (BCLK), U4.30 (GPIO45)
/CS: J3.7, U4.16 (GPIO10)
/DC: J3.6, U4.5 (GPIO5)
/DIN: U3.5 (DIN), U4.28 (GPIO47)
/GPIO1: J5.3, U4.41 (GPIO1)
/GPIO2: J5.4, U4.40 (GPIO2)
/GPIO3: J5.5, U4.13 (GPIO3)
/GPIO38: J5.6, U4.35 (GPIO38)
/GPIO39: J5.7, U4.36 (GPIO39/MTCK)
/GPIO40: J5.10, U4.37 (GPIO40/MTDO)
/GPIO41: J4.2, J5.11, U4.38 (GPIO41/MTDI)
/GPIO42: J4.4, J5.12, U4.39 (GPIO42/MTMS)
/GPIO46: J5.14, U4.14 (GPIO46)
/GPIO48: J5.15, U4.29 (GPIO48)
/I2C_SCL: J1.4, U4.15 (GPIO9)
/I2C_SDA: J1.3, U4.12 (GPIO8)
/IR_DATA: J2.3, U4.11 (GPIO18)
/IR_LED: R1.1, U4.10 (GPIO17)
/LED: D1.4 (DIN), U4.9 (GPIO16)
/LRC: U3.7 (LRC), U4.27 (GPIO21)
/RES: J3.5, U4.4 (GPIO4)
/SCL: J3.3, U4.18 (GPIO12)
/SDA: J3.4, U4.17 (GPIO11)
/SW1: SW1.1, U4.19 (GPIO13)
/SW2: SW2.1, U4.20 (GPIO14)
/VR_BTN: U2.8 (SW-b), U4.8 (GPIO15)
/VR_X: U2.2 (VR1-2), U4.7 (GPIO7)
/VR_Y: U2.5 (VR2-2), U4.6 (GPIO6)
GND: D1.3 (VSS), D2.3 (VSS), D5.1 (K), J1.1, J2.2, J3.1, J4.3, J5.8, J5.9, SW1.2, SW2.2, U2.1 (VR1-1), U2.6 (VR2-3), U2.7 (SW-a), U3.2 (GND), U3.4 (GAIN), U4.22 (GND), U4.23 (GND), U4.24 (GND), U4.44 (GND)
unnamed: D1.2 (DOUT), D2.4 (DIN)
unnamed: D5.2 (A), R1.2
unnamed: LS1.2, U3.9 (OUTN)
unnamed: LS1.1, U3.8 (OUTP)
VCC: J5.16, U3.1 (Vin), U4.21 (5V)

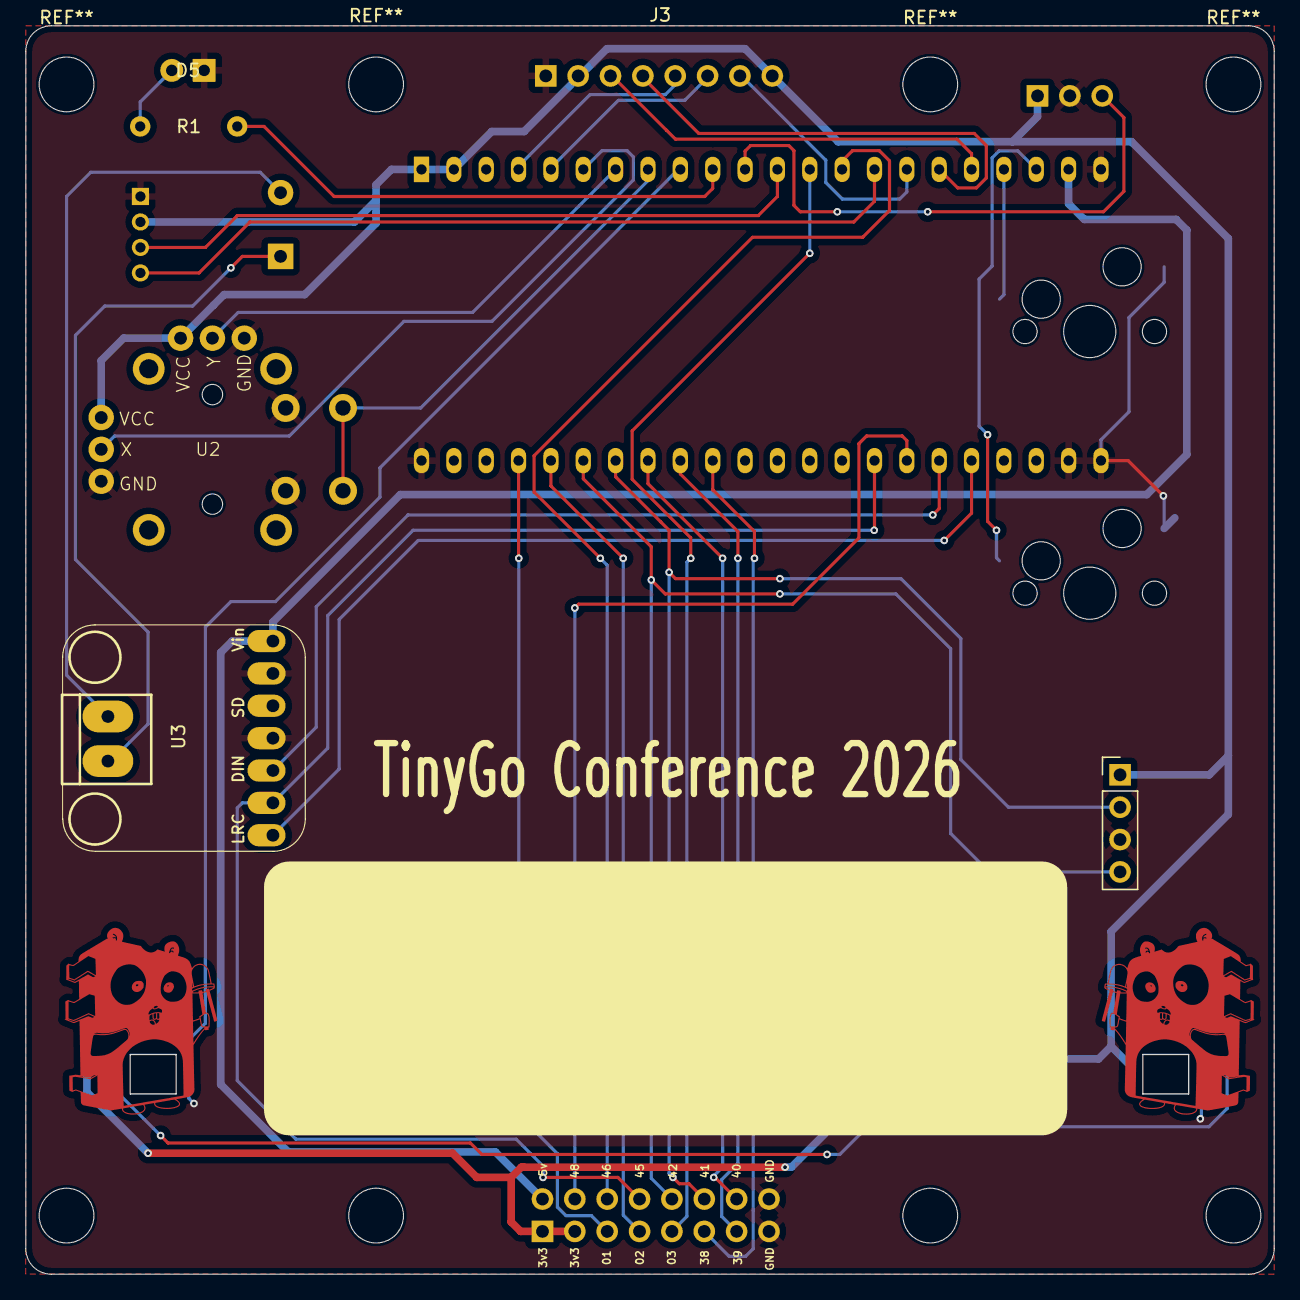
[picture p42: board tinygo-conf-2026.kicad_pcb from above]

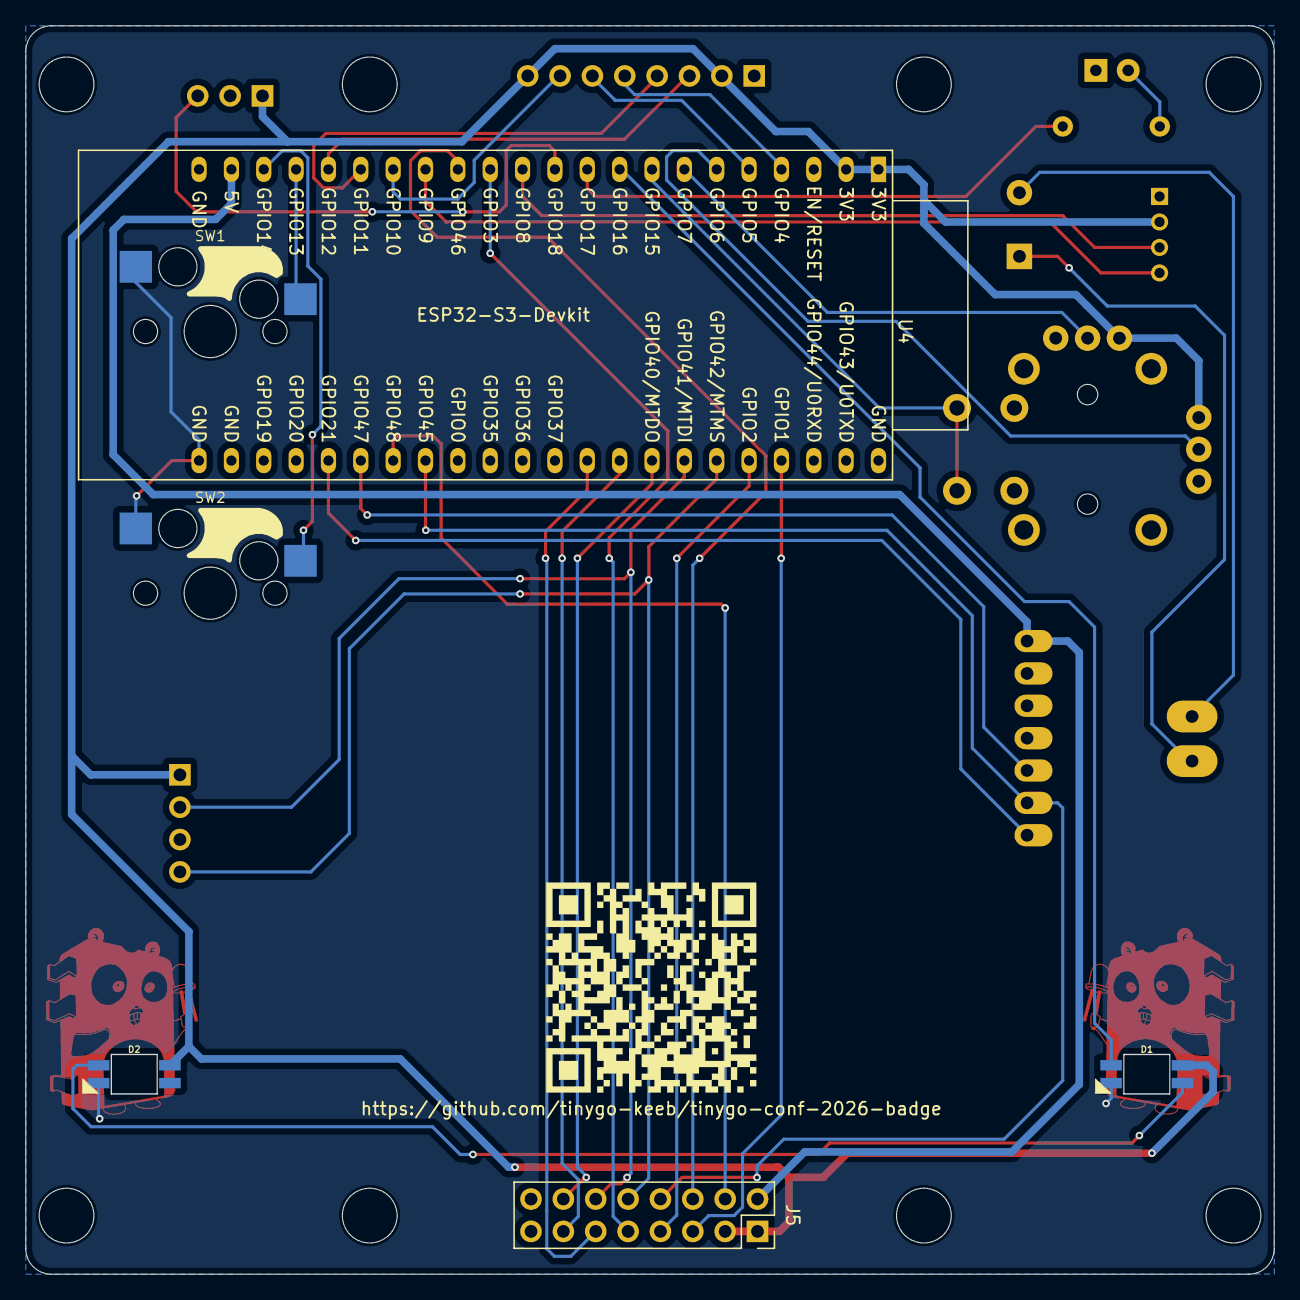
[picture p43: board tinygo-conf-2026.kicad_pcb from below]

Board: 2 copper layers, 98.0 x 98.0 mm, 16 parts (7 on the bottom side), 35 nets.

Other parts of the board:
QR*****: https://github.com/tinygo-keeb/tinygo-conf-2026-b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; tinygo-conf-badge-qr-code

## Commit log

2026-08-24 add kicad files
    [tinygo-conf-2026-B_Cu.gbr, tinygo-conf-2026-B_Mask.gbr, tinygo-conf-2026-B_Paste.gbr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]
2026-08-26 フットプリントライブラリとシンボルのファイル追加と更新
    [tinygo-conf-2026.kicad_pcb, tinygo-conf-2026.kicad_sch]
2026-09-14 ファイルを追加してリネーム
    [tinygo-conf-2026-B_Cu.gbr, tinygo-conf-2026-B_Mask.gbr, tinygo-conf-2026-B_Paste.gbr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]
2026-09-15 配線変更と基板の穴を追加
    [tinygo-conf-2026-B_Cu.gbr, tinygo-conf-2026-B_Mask.gbr, tinygo-conf-2026-B_Paste.gbr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]
2026-09-19 温湿度センサーのGPIOがUSBとかぶっていたので変更
    [tinygo-conf-2026-B_Cu.gbr, tinygo-conf-2026-B_Mask.gbr, tinygo-conf-2026-B_Paste.gbr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]
2026-09-20 PSRAM用のGPIOを使わないように再配線
    [tinygo-conf-2026-B_Cu.gbr, tinygo-conf-2026-B_Mask.gbr, tinygo-conf-2026-B_Paste.gbr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]
2026-09-24 TinyGo ファームウェアを追加
    firmware/ に ESP32-S3-DevKit 向けの TinyGo ファームウェアの土台を追加。
    - badge/: 回路図から抽出したピン割り当てと各ペリフェラルの初期化ヘルパー
    - ws2812s3/: ESP32-S3 (240MHz) 用の WS2812B ドライバ
    - examples/: blink, display, input, aht21b, i2cscan, ir, demo
    - badge/i2c.go: TinyGo の ESP32 I2C ドライバの問題 (プルアップなしの
    バスで Configure が止まる、NACK 未検出、FIFO の残り) を回避する
    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
2026-09-24 赤外線送受信の修正
    - 受信コールバック (GPIO 割り込み内) で println せず、volatile 変数経由で
    メインループから出力するように変更 (割り込み内出力で固まる問題の対策)
    - NEC 送信のビット順を LSB first に修正し、32bit の配置を irremote の
    Data.Code と同じにする (受信した code をそのまま再送可能)
    - README に割り込み内で出力しない旨を追記
2026-09-25 I2S (MAX98357) の音声出力を追加
    - firmware/i2s: ESP32-S3 の I2S0 + GDMA をレジスタ直接操作で実装した
    16bit ステレオ出力ドライバ (ESP-IDF v5.1 の i2s_ll.h / gdma_ll.h を移植)
    - badge.NewAudio と正弦波の ToneGenerator (単音・和音、フェード付き)
    - examples/audio: 音階、メロディ、純正律の和音進行 (C G Am F)、ジョイスティック音
    - examples/audiotest: レジスタとピンのトグル状況の診断出力と 1kHz 連続正弦波
    - README に I2S の実装方針と MAX98357 の SD ピンの注意を追記
2026-09-25 Grove の DHT20 を読む example を追加
    - examples/dht20: Grove (I2C0) の DHT20 (AHT20 互換) を aht20 ドライバで読む
    - badge.go に Grove ケーブルの挿す向き (1 ピンの四角パッドが GND) を記載
2026-09-25 ジョイスティックにセンター補正、デッドゾーン、飽和処理を追加
    - Calibrate で起動時に中立位置を実測する
    - 半径方向にデッドゾーン (既定 80) と飽和 (既定 850) を掛け、
    出力を半径 1000 の円の内側に収める
    - X 軸の反転を InvertX フィールドにする (配線上、右が +X になるよう既定 true)
2026-09-25 Wi-Fi (espradio) の example を追加
    - examples/wifi-httpget: httpbin.org に net/http で GET
    - examples/wifi-server: AHT21B の温湿度を返す HTTP サーバー (httphi)
    - examples/wifi-joystick: ジョイスティックとスイッチの状態をブラウザに
    リアルタイム表示 (デッドゾーン・飽和の切り替え付き)
    - firmware/wifi: 接続失敗時にチップをリセットして再試行する wifi.Connect。
    espradio を自モジュールから import すると init 順の都合で RAM が約 70KB
    増えるため、netlink.Netlinker を受け取る形にして espradio は main で import する
    - badge.Reset (RTC_CNTL のソフトリセット)
    - Makefile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
2026-09-25 LCD のちらつき対策としてフレームバッファを追加
    - badge.Framebuffer: 1 画面分 (RGB565) のオフスクリーンバッファに描いて
    Display で一括転送する。tinyfont の描画先としてそのまま使える
    - 転送は 16 行ごとに分割し、合間に runtime.Gosched で他の goroutine
    (espradio の BLE/Wi-Fi のタスク) に実行を譲る
    - examples/demo をフレームバッファ描画に変更し、約 30fps に揃える
2026-09-25 WS2812 ドライバを BLE/Wi-Fi 動作中でも正しく送れるように修正
    - フレーム全体を割り込み禁止で送る。バイトごとに割り込みを許可すると
    BLE の割り込みで 50us 以上の隙間ができ、WS2812B が途中でラッチして
    後続の LED に色が届かなかった
    - 送信前にマスク 0 で 1 バイト空回しして命令キャッシュを温める。
    散発的な送信では開始時のキャッシュミスで先頭ビットの High が伸び、
    先頭の LED が緑に固定されていた
    - ビットバンギング関数は空回しと本番でコードを共有するよう noinline
2026-09-25 BLE (espradio) の example と bluetooth パッケージのローカル修正を追加
    - examples/ble-scanner: 周囲のデバイスをスキャンして表示
    - examples/ble-sensor: 温湿度 (Environmental Sensing)、WS2812B 2 個の色
    書き込み、ボタン通知、LED の自動/手動モードを公開するペリフェラル。
    アドバタイズ名と LCD にチップ固有の ID (badge.SerialNumber、eFuse の MAC
    から生成) を表示し、ワークショップで複数台を見分けられるようにする
    - examples/ble-sensor/webble.html: Web Bluetooth で接続して操作するページ
    - third_party/bluetooth: tinygo.org/x/bluetooth v0.16.0 のコピーに
    Find By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
2026-09-25 リモコンの学習・送信アプリとフラッシュ保存 (flashstore) を追加
    - examples/irlearn: 受信モジュールの生パルス長を記録して 38kHz キャリアで
    再生する (NEC 以外のリモコンにも対応)。一覧、送信 (SW1)、メニュー (SW2)
    による削除と改名、末尾の "+ Register" からの登録、ジョイスティックでの
    名前入力
    - flashstore: ESP32-S3 の ROM 関数 (esp_rom_spiflash_*) を CGo から絶対
    アドレスで呼んでフラッシュを読み書きする。TinyGo のイメージヘッダが
    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
2026-09-25 ジョイスティックの可動範囲に合わせて正規化を修正、計測用 joyraw を追加
    - スティックの可動範囲が絞られ ADC 生値は中心から ±16000 程度しか動かないため、
    Joystick に Range (既定 16000) を追加してそれで正規化する。DeadZone は 50 に変更
    - examples/joyraw: 生値と min/max を出力する可動範囲の計測用 example
    - examples/wifi-joystick: ポーリングを 66ms に変更し、軌跡を残す keep trail と clear を追加
2026-09-25 README.md を追加
2026-09-25 KiCad のロックファイルと自動保存ファイルを .gitignore に追加
2026-09-25 Makefile を example ごとのべた書き smoketest に変更
    - パターンルールや変数をやめ、全 example の tinygo build コマンドを 1 行ずつそのまま書く
    (tinygo-keyboard の smoketest に倣う)。書き込みは該当行をコピーして flash に変える
    - Wi-Fi の example だけは SSID/PASS を環境変数から埋め込む flash-wifi-* を残す
    - 生成物の out/ を .gitignore に追加し、README の書き込み手順を更新
2026-10-06 全デバイスを一度に動作確認する selftest を追加
    - LCD (起動時に赤緑青の全面表示)、LED、SW1/SW2、ジョイスティック (ボタンと上下左右)、
    AHT21B、Grove I2C スキャン、赤外線の自己受信、I2S を 1 画面で確認する
    - 自動で判定できる項目がすべて済むと ALL OK を表示する。判定結果はシリアルにも出力
    - ジョイスティックのセンター位置は起動直後に測る
2026-10-06 音ゲーの example (rhythm) を追加
    - 上から降ってくるノーツに合わせて 5 つのキー (ジョイスティックの左、上か下、右と
    SW2、SW1) を押す。EASY / NORMAL、判定は PERFECT / GOOD / MISS、結果画面でランク表示
    - BGM (メロディ、ベース、キック、ハイハット) はその場で合成し、メロディの音の高さと
    レーンを対応させる。ゲームの時刻はスピーカーから出ている音の位置に合わせる
    - 入力は 2ms ごとに goroutine で読み、押した瞬間の時刻で判定する。ジョイスティックは
    浅めのしきい値と広めの判定幅にし、ずれの平均をシリア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
2026-10-06 kicad関連のファイルをhardware以下に移動
    [tinygo-conf-2026-B_Cu.gbr, tinygo-conf-2026-B_Mask.gbr, tinygo-conf-2026-B_Paste.gbr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]
2026-10-06 ファイルの移動忘れ
2026-10-06 webble.html の公開 URL を追記し、BLE example の書き込み手順を直す
    - README と ble-sensor のコメントに https://conf.tinygo-keeb.org/2026/conf2026badge/ を追記
    - ble-sensor / ble-scanner のコメントに残っていた make flash-ble-* (Makefile の変更で
    なくなった) を tinygo flash のコマンドに置き換え、デバッグは -tags bledebug と書く
2026-10-08 Build guide (#2)
    * ビルドガイド作業中
    * 写真をpngに変更
    * ビルドガイド追記
    * パーツを追加
    * LEDの数を明記
    * フィードバックの修正
    * 写真を差し替え
    * ファイルの移動忘れ
    * TinyGo ファームウェアを追加
    バスで Configure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
2026-10-09 Add all programs (#3)
    * 全てのプログラムを合体したallを作成
    * スロットゲームに絵柄追加
    * 戻る操作を変更&画面のちらつきを除去
2026-10-15 README にケースデータ (MakerWorld) へのリンクを追加
